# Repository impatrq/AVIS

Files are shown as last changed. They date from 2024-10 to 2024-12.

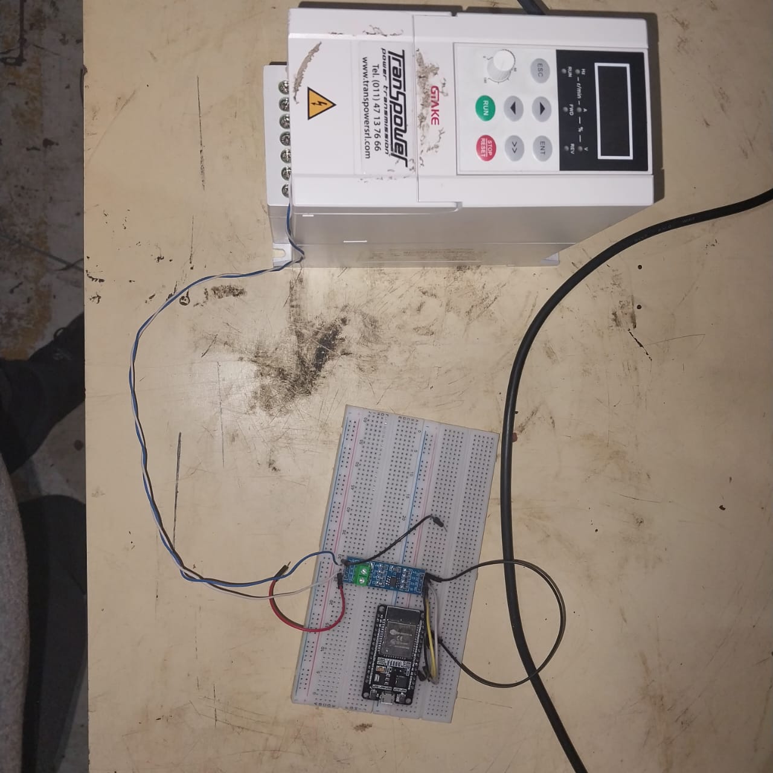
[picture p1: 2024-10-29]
variadores de frecuencia/pruebas con el osciloscopio/circuito.jpeg

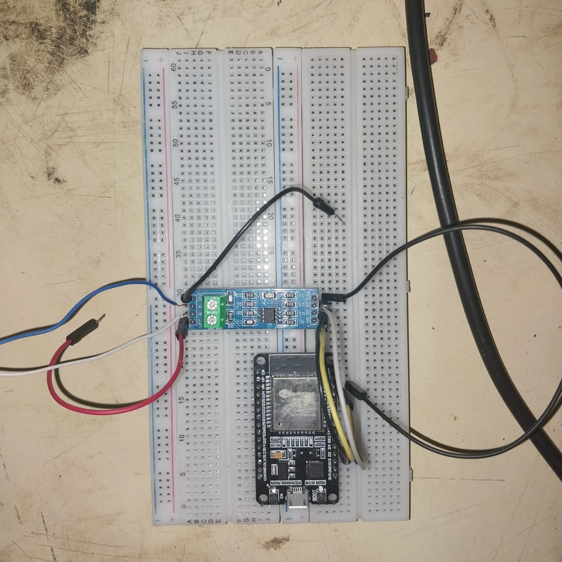
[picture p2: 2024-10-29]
variadores de frecuencia/pruebas con el osciloscopio/circuitov2.jpeg

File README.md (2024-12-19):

<div align="center">

# [S  K  Y  ⅃  ꟻ](https://estebanlautaro.github.io/Paginaweb-SKYFLY/)

Captura de pantalla 2024-11-19 194901

&nbsp;

| Página web | Email | Instagram | TikTok |
|---|---|---|---|
|[Paginaweb-SKYFLY](https://estebanlautaro.github.io/Paginaweb-SKYFLY/)|skyflyproyect@gmail.com|[skylf.proyect](https://www.instagram.com/skylf.proyect/)|[skyfly826](https://www.tiktok.com/@skyfly826)|

&nbsp;

</div>

## ¿De que se trata nuestro proyecto?

Nuestro proyecto es continuar con el simulador de vuelo que empezo el grupo llamado "AVIS" en 2019, destinado a practicar maniobras y replicar las condiciones de vuelo reales dentro de una cabina que simula los movimientos del avion. El propósito principal será facilitar la realización de prácticas didácticas, proporcionando a los usuarios un entorno seguro y controlado para mejorar sus habilidades de vuelo y familiarizarse con diferentes escenarios y situaciones aeronáuticas. Este tipo de simuladores se utilizan tanto con fines de entrenamiento de pilotos como para el entretenimiento de entusiastas de la aviación. Para mas informacion, entrar a las carpetas que estan en el repositorio.

## Tecnologías utilizadas 

### Entorno Virtual
- Flight Simulator 2020
- SimVar Watcher
  
### Software de programación
- ArduinoUNO
- Thonny

#### Drivers de ArduinoUNO
- ESP32_DEVKIT
- MPU6050_light

### Componentes 
- #### Placa PCB con:
  - ESP32 (30 pines)
  - MPU6050
  - Potenciometro digital X9C103S
  - Dos optoacopladores 4N25
  - Dos resistencias de 330 ohms
  - Dos resistencias de 10 Kohms
    
- #### Panel de Control:
  - Impresión 3D del Panel de Control
  - ArduinoUNO R3
  - Cable de Datos para el Arduino
  - 9 switches On/Off
  - 3 Pulsadores
  - Llave selectora de 6 estados

### Software del Panel de Control:
- Mobiflight
- FSUIPC

## Integrantes:

Somos un grupo de alumnos de 7°2da AV de la E.E.S.T. N°7 "Taller Regional Quilmes" (IMPA).

<div align="center">



</div>

### Lautaro Esteban

    📷 Instagram: @lauty.esteban
    📧 Email: lautyesteban14@gmail.com
    🗞️ LinkedIn: Lautaro Sebastian Esteban
    🌐 Github: https://github.com/estebanlautaro

### Agustin Brizuela:

    📷 Instagram: @agustiin.brizuela 
    📧 Email: brizuu750@gmail.com 
    🗞️ LinkedIn: Agustin Lionel Brizuela 
    🌐 Github: https://github.com/brizuu750

### Marco Jofiel Godoy Baldovino:

    📷 Instagram: @jofiel_godoy  
    📧 Email: markbaldj@gmail.com 
    🗞️ LinkedIn: Marco Baldovino
    🌐 Github: https://github.com/MarkingRNT

### Santiago Rubio:

    📷 Instagram: @santy_201205
    📧 Email: santy201205@gmail.com
    🗞️ LinkedIn: Santiago Rubio
    🌐 Github: https://github.com/SantiagoRubio

### Lucas David Meabrio:

    📷 Instagram: @lucass_meab
    📧 Email: meabriolucas@gmail.com
    🗞️ LinkedIn: Lucas Meabrio
    🌐 Github: https://github.com/LucasMeabrio

### Leandro Flores:

    📷 Instagram: @lean.floresss
    📧 Email: leandro200flores@gmail.com
    🗞️ LinkedIn: Leandro Flores
    🌐 Github: https://github.com/lean1712flores

### Santiago Leiva:

    📷 Instagram: @leivva.s
    📧 Email: santiagoleiva745@gmail.com 
    🗞️ LinkedIn: Santiago Leiva
    🌐 Github: https://github.com/SantyLeiva

### Emiliano Romo Cordoba:

    📧 Email: romoemiliano324@gmail.com
    🗞️ LinkedIn: Emiliano Romo Cordoba 
    🌐 Github: https://github.com/RomoCordoba

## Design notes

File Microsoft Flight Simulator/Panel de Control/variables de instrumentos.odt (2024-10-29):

INSTRUMENTOS:

velocimetro

no confundir airspeed indicated con true, me parece que se usa la indicada

altimetro

variometro (indicador de velocidad vertical)

horizonte artificial:

según chatgpt

lo que encontre yo es esto

si esta congelado y un flag, es el attitude indicator en ingles

brujula (giro direccional??? quien le dice asi xd)

~~NO~~ usar

turn indicator:

no estoy 100% seguro que ese se use el de arriba

NAV LOC

NAV VOR/ GLIDE SLOPE(GS)

ahora el gs

preparate para el adf xd

reloj

no encontre, no tengo ni idea

amperimetro/voltimetro

si quieren poner esto en el panel pidanlo

temp y presion de aceite

no se la diferencia entre estos y los que vienen

SI USAR

temp de gas de escape y flujo de combustiblre

egt = exhaust gas temperature = temp d gas de escape

ind combustible

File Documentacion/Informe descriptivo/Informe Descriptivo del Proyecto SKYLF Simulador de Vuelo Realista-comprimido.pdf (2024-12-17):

# Informe Descriptivo del Proyecto SKYLF: Simulador de Vuelo Realista

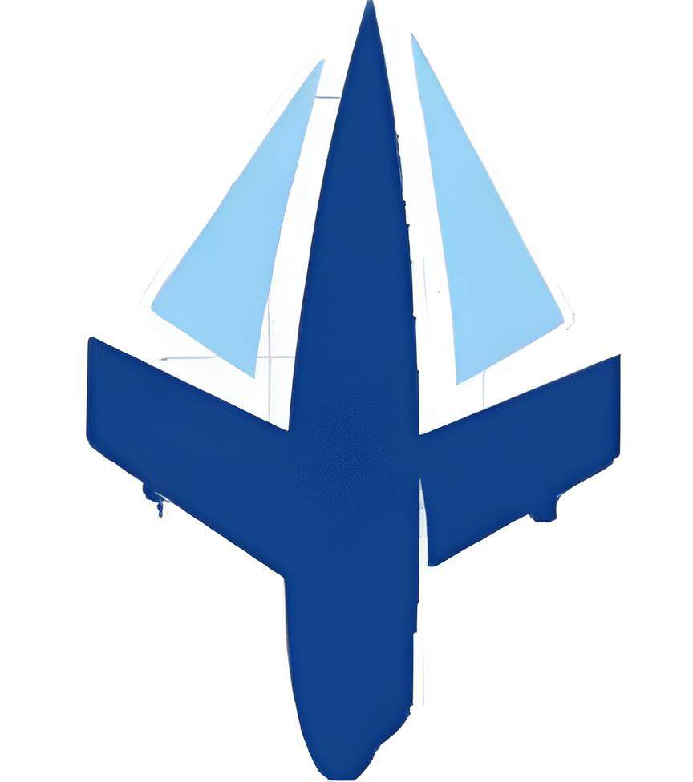
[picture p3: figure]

## Título:

Simulador de Vuelo Realista con Control de Variadores de Frecuencia y Panel de Instrumentos Físicos

## Nombre del Proyecto y Año:

SKYFLY - 7° 2° Aviónica

## Link a la Web:

https://estebanlautaro.github.io/Paginaweb-SKYFLY/

## Link a Trello:

https://trello.com/b/u9Dn0bU8/kanban

## Link a GitHub:

https://github.com/brizuu750/SKYLF

## Link a Redes Sociales:

●
Instagram: | https://www.instagram.com/skylf.proyect/
- Tiktok: | https://www.tiktok.com/@skyfly826?_t=8qnCGQhRKsA&_r=1

## Presentación del Equipo:

Lauaro Eseban:

Mail: Lautyesteban14@gmail.com

Linkedin: Lautaro Sebastian Esteban

Instagram: @lauty.esteban

Santiago Rubio:

Mail: Santy201205@gmail.com

Linkedin: Santiago Rubio

Instagram: @santy_201205

Lucas Meabrio:

Mail: Meabriolucas@gmail.com

Linkedin: Lucas Meabrio

Instagram: @lucass_meab

Leandro Flores:

Mail: leandro200flores@gmail.com

Linkedin: Leandro Flores

Instagram: @lean.floresss

Agustin Brizuela:

Mail: brizuu750@gmail.com

Linkedin: Agustin Lionel Brizuela

Instagram: @agustiin.brizuela

Santiago Leiva:

Mail: Santiagoleiva745@gmail.com

Linkedin: Santiago Leiva

Instagram: @leivva.s

Emiliano Romocordoba:

Mail: Romoemiliano324@gmail.com

Linkedin: Emiliano Romo Cordoba

Jofiel Godoy Baldovino:

Mail: Markbaldj@gmail.com

Linkedin: Marco Baldovino

Instagram:@jofiel_godoy

## Foto de cada integrante:

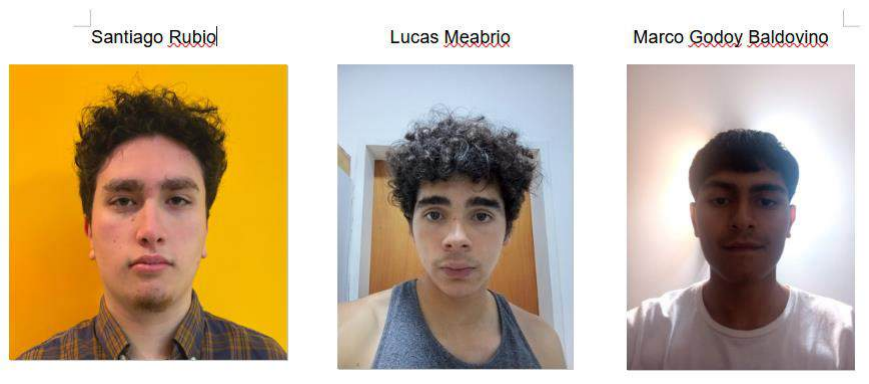
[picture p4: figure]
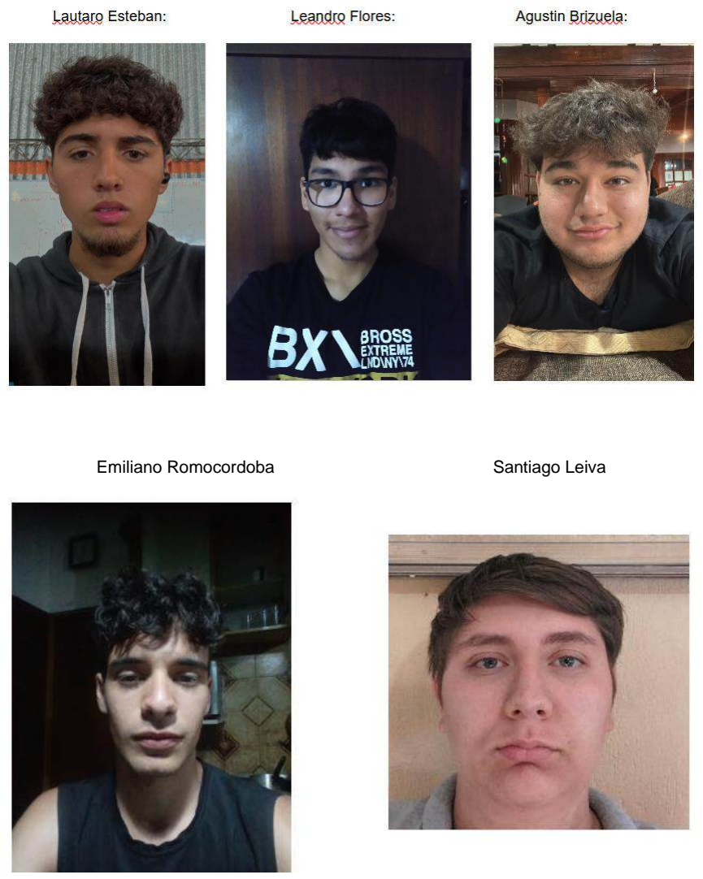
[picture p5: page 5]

Emiliano Romocordoba | Santiago Leiva

Foto grupal:

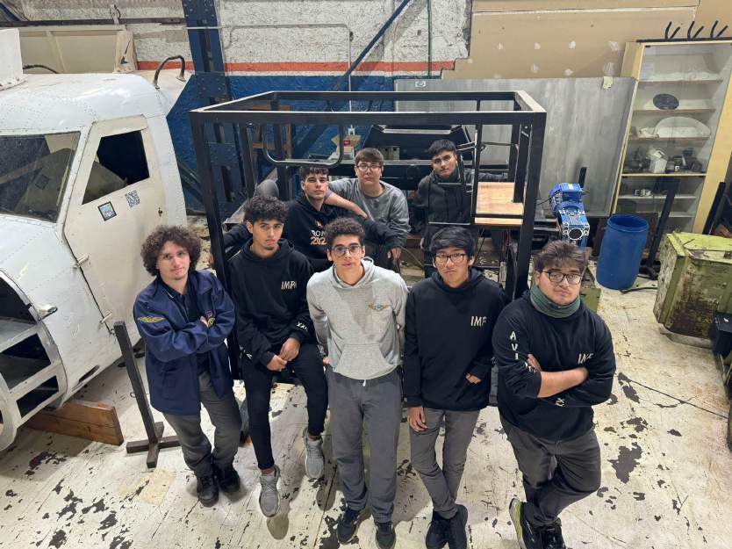
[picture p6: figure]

## Horas dedicadas por cada integrante:

Participaron un total de 8 personas en un promedio de 14 hs semanales durante 28 semanas aproximadamente

## Índice General

1. Introducción
2. Objetivo
3. Descripción de la Solución Buscada
4. Segmento Destino y Alcance
5. Captura Representativa del Proyecto
6. Diagrama en Bloques del Proyecto
7. Resultado Conseguido
8. Software
9. Sistema Embebido
10. Electrónica
11. Estructura
12. Anexo

## 1. Introducción

Este proyecto de Simulador de Vuelo Realista, basado en la cabina del Cessna 152, replica las maniobras y controles de la aeronave mediante la integración de un panel físico de control y un sistema de visualización interactuando con Flight Simulator 2020. Se implementa un circuito de comunicación mediante un Arduino UNO y un ESP32 que permiten gestionar diversos sistemas y enviar comandos a través de variables de comunicación específicas, sincronizando los instrumentos físicos con el simulador virtual. Además, el simulador utiliza un sistema de control de motores con variadores de frecuencia y sensor de movimiento MPU6050 para añadir realismo en el control de vuelo.

## 2. Objetivo

Objetivo General:

Construir un simulador de vuelo con una interfaz de usuario realista, que permita experimentar el control de una aeronave tipo Cessna 152 mediante un panel físico conectado a Flight Simulator 2020.

Objetivo Específico:

Integrar un sistema de variadores de frecuencia, Arduino UNO y ESP32, junto con un panel de control que permita al usuario activar sistemas de vuelo, como el control de luces, bomba de combustible y buses aviónicos, replicando el entorno real de un avión en el simulador virtual.

## 3. Descripción de la Solución

El simulador incluye dos sistemas principales: un Panel de Control y un Panel de Visualización de Instrumentos, con un esquema de comunicación que integra varios componentes para emular los controles de un avión real.

Panel de Control

El Panel de Control cuenta con 9 interruptores de palanca, 3 pulsadores, y una llave selectora rotativa de 6 estados. Este panel físico permite al usuario activar sistemas esenciales de la aeronave en el entorno virtual de Flight Simulator 2020, mediante la integración de MobiFlight y Arduino UNO. Algunos de los sistemas principales controlados por el panel incluyen:

- Bomba de Combustible: Activa una bomba de combustible que permite el cebado inicial del motor.

- Luces (BCN, LAND, TAXI, NAV, STRB): Controla las luces exteriores del avión para el despegue, aterrizaje y condiciones de vuelo específicas.
- Interruptores de Bus Aviónico: Activa los sistemas de navegación y comunicación de la aeronave.
- Tubo Pitot: Controla el calentador del tubo Pitot para evitar el congelamiento.
- Primer: Se encarga de inyectar combustible a los cilindros del motor antes de arrancarlo, facilitando el arranque en condiciones especialmente frías.
- Magnetos: Distribuyen corriente eléctrica a las bujías, gestionadas por una llave rotativa de 6 estados. Para comunicar la llave selectora tuvimos que hacer un código que se encargue de mandar los “Events id” para las posiciones del magneto dependiendo de la actual posición de la llave selectora ya que al usar Mobiflight, algunas posiciones son erróneas (se utilizan como una forma de interactuar entre diferentes sistemas del simulador), pero en el código las posiciones andan bien. Las partes más importantes del código son:

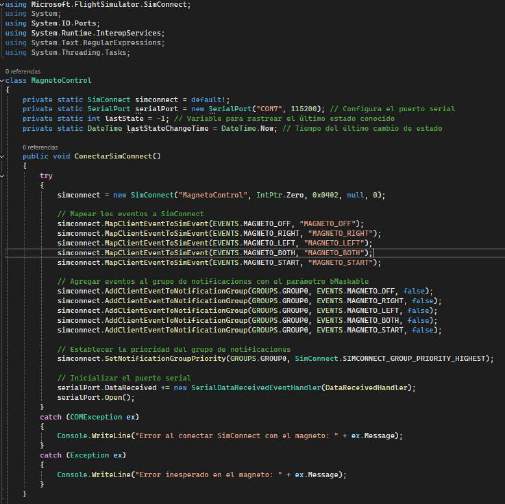
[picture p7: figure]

Se ingresan las librerías necesarias y los events id que se van a usar:

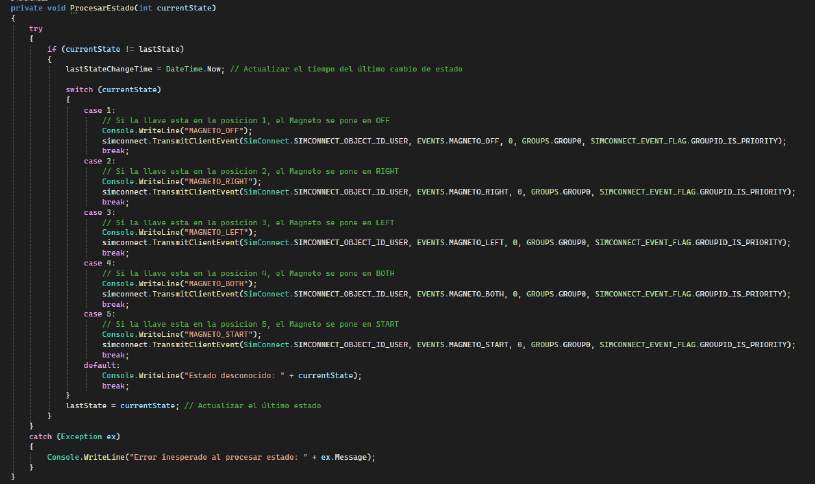
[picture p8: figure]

El código enviá estos events id al propio Flight Simulator dependiendo de la posición de la llave selectora

El Arduino UNO es el microcontrolador principal del panel de control y se configura mediante MobiFlight para ejecutar comandos específicos en Flight Simulator 2020 según los interruptores activados. Esto asegura que cada acción en el panel tenga un reflejo preciso en el simulador virtual, mejorando la inmersión en el entorno de vuelo.

Paso a Paso de configuración de palancas para vincularlas con MobiFlight y el FS2020:

1. Conectamos el Arduino UNO al MobiFlight y el FSUIPC7
2. Asignamos un Pin del 2 al 13 del Arduino UNO a uno de los terminales de la palanca (En nuestro caso lo pusimos al pin 8 pero puede ser cualquiera)
3. Seleccionar en MobiFlight la pestaña de "MobiFlight Modules"
4. Para no tener inconvenientes actualizar el firmware así el MobiFlight detecte correctamente el la Arduino UNO
5. En la barra inferior ir a la pestaña de "Add Device" para agregar un dispositivo que en nuestro caso es una palanca.
6. Luego le asignamos a la palanca el nombre con el que queramos que se identifique, siendo en este caso "Tubo Pitot" para la función de la palanca que es sobre el Calentador del Tubo Pitot

7. Poner en la "Configuración de Pin" el pin que le asignamos a la palanca (en nuestro caso el Pin 8 de la Arduino UNO)
8. En el Menú principal crear una configuración de entrada en el "Input Configs"
9. Para editar la configuración selecciona a la derecha de la fila en "Edit"
10. Luego seleccionar los dispositivos conectados al MobiFlight
11. Seleccionar en el Action Type el "FSUIPC - Offset" para luego asignarle la acción al dispositivo que hayamos conectado (en nuestro caso la palanca)
12. Dentro de la configuración de entrada se encuentran las configuraciones para cuando se activa la palanca "On Press" y cuando está del lado contrario "On Release"
13. Para la configuración del Offset nos fijamos en el manual de Offset del FSUIPC que está en internet para buscar la acción de la palanca, y nos dice cuál código de Offset tiene que ir.
14. En nuestro caso buscamos el del calentador del tubo pitot. Por lo que ponemos el que nos dice "029C"
15. Para que el Calentador del tubo pitot del Cessna 152 se active en simultáneo a la palanca que conectamos al FS2020, le asignamos "1" como valor de seteo.
16. En "On Release" de igual forma poner el mismo código de Offset pero que cuando se baje la palanca que el calentador se apague ponemos "0" como valor de seteo
17. Luego de esto al probar la palanca que vinculamos a dispositivo que sea (en nuestro caso el calentador del tubo pitot), se tendría que activar simultáneamente

Comunicación con el Variador de Frecuencia y Sistema de Control de Movimiento

Para lograr una experiencia de vuelo más realista, el simulador utiliza un variador de frecuencia GK500-2T2.2B controlado por un ESP32 y un potenciómetro digital para gestionar el movimiento de los motores, lo que permite simular inclinaciones en los ejes de cabeceo y alabeo. La configuración del variador de frecuencia y el sistema de comunicación están organizados de la siguiente forma:

- ESP32 y Potenciometro digital: El ESP32 envía comandos al potenciómetro digital a través de los pines de control (UP, DOWN, CS) para ajustar su resistencia.El potenciómetro digital modifica los valores eléctricos que afectan directamente el comportamiento de los variadores de frecuencia, lo que impacta en el movimiento de los motores trifásicos y, en consecuencia, en la inclinación de la cabina del simulador.
- Configuración de Pines:
- Conexión del MPU6050:

- VCC del MPU6050 a 3.3V del ESP32.
- GND del MPU6050 a GND del ESP32.
- SDA del MPU6050 a GPIO21 del ESP32.
- SCL del MPU6050 a GPIO22 del ESP32.
- Conexión de los Potenciómetros Digitales
a. Para el primer potenciómetro:
- CS_PIN a GPIO15 del ESP32.
- INC_PIN a GPIO14 del ESP32.
- UP_DOWN_PIN a GPIO13 del ESP32.
- VW va al GND del variador 1
- VH y VL van a dos pines del variador 1
- VCC del potenciómetro a la entrada analógica del variador 1 (AI1).
- GND del potenciómetro a GND común del variador 1
b. Para el segundo potenciómetro:
- CS_PIN a GPIO32 del ESP32.
- INC_PIN a GPIO33 del ESP32.
- UP_DOWN_PIN a GPIO25 del ESP32.
- VW va al GND del variador 2
- VH y VL van a dos pines del variador 2
- VCC del potenciómetro a la entrada analógica del variador 2 (AI1).
- GND del potenciómetro a GND común del variador 2.
- Conexión de los optoacopladores y resistencias:
a. Para el primer optoacoplador:
- Anodo del led va a la primera resistencia de 330 Ω y luego al GPIO27 del ESP32
- Cátodo del led va a GND del esp32
- Colector va conectado a el puerto x1 del variador 1 y también conectado a la primera resistencia de 10 KΩ y luego va al VCC de la fuente
- Emisor del optoacoplador va a COM del variador 1 y también va a GND de la fuente
b. Para el segundo optoacoplador:
- Anodo del led va a la segunda resistencia de 330 Ω y luego al GPIO12 del ESP32
- Cátodo del led va a GND del esp32
- Colector va conectado a el puerto x2 del variador 1 y también está conectado a la segunda resistencia de 10 KΩ y luego va al VCC de la fuente
- Emisor del optoacoplador va a COM del variador 1 y también va a GND de la fuente
c. Para el tercer optoacoplador:

- Anodo del led va la tercera resistencia de 330 Ω y luego al GPIO18 del ESP32
- Cátodo del led va a GND del esp32
- Colector va conectado a el puerto x1 del variador 2 y también está conectado a la tercera resistencia de 10 KΩ y luego va al VCC de la fuente
- Emisor del optoacoplador va a COM del variador 2 y también va a GND de la fuente
d. Para el cuarto optoacoplador:
- Anodo del led va la cuarta resistencia de 330 Ω y luego al GPIO19 del ESP32
- Cátodo del led va a GND del esp32
- Colector va conectado a el puerto x2 del variador 2 y también está conectado a la cuarta resistencia de 10 KΩ y luego va al VCC de la fuente
- Emisor del optoacoplador va a COM del variador 2 y también va a GND de la fuente
3. Sensor de Movimiento MPU6050: Integrado al ESP32, el MPU6050 detecta la inclinación y aceleración en tiempo real, lo que permite ajustar los movimientos del simulador para reflejar las maniobras de vuelo de manera más precisa. Este sensor es crucial para sincronizar el sistema físico con los cambios en el entorno virtual del Flight Simulator 2020.

Panel de Visualización de Instrumentos

Este panel de visualización está diseñado para mostrar los datos de vuelo en una pantalla de 18 pulgadas, reflejando los instrumentos de la aeronave. La comunicación de los datos de vuelo se realizaría mediante Air Manager o Pop Out Panel Manager, que gestionan las variables de Flight Simulator 2020. Este diseño permite una representación en tiempo real de los parámetros del simulador, ajustando el diseño para que se asemeje al de un Cessna 152.

Flight Simulator 2020

Utilizamos Microsoft Flight Simulator - 40th Anniversary Edition, compatible con herramientas externas de comunicación que extraen variables en tiempo real, como Simvar Watcher.

Simvar Watcher y Extracción de Variables

El Simvar Watcher facilita la lectura de variables seleccionadas del simulador, configurado con las librerías SimConnect y otros archivos DLL y CFG, permitiendo acceder a las lecturas en tiempo real. Las variables se agrupan para la lectura de datos de instrumentos (altímetro, velocímetro, etc.) y control de movimiento.

Para la integración de Simvar Watcher con Flight Simulator, utilizamos códigos en C# en Visual Studio 2022. Estos códigos gestionan la conexión y extracción de

variables, que se dividen según los instrumentos que controlan (altímetro, brújula, velocímetro, etc) y un código para los movimientos y aceleraciones del avión.

Códigos Generales:

- Program.cs: Este código configura y gestiona la comunicación entre el simulador de vuelo y múltiples sistemas de instrumentos y controles, permitiendo que cada uno reciba y procese datos en tiempo real.
- SimConnectApp.csproj: Este código configura un proyecto de .NET 8.0 que genera un ejecutable (Exe) para la plataforma x64. Define referencias y dependencias necesarias, incluyendo System.IO.Ports para manejar la comunicación por puertos seriales y SimConnect para interactuar con Microsoft Flight Simulator. También, especifica la ruta de salida para los binarios compilados y define un objetivo post-construcción que copia los archivos SimConnect.dll y SimConnect.cfg necesarios a la ubicación de salida del proyecto.

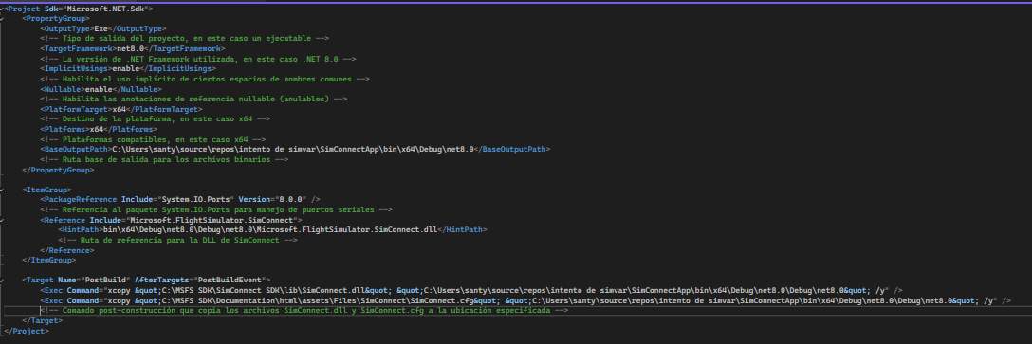
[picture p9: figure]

Códigos de Instrumentos:

Cada instrumento está asignado a un código específico que se comunica con el simulador. Los siguientes están hechos para ser comunicados con una aplicación externa, como el Air Manager en caso de los instrumentos analógicos, y en caso de que se desee añadir alguno digital, se pueden encontrar variantes a este como el pop out manager. Además, son los encargados de la sincronización con mobilight, por lo que permite que funcionen tanto el panel de instrumentos como el de control. Por ejemplo:

Altímetro.cs: Extrae la altura en tiempo real.

Variómetro.cs: Controla la velocidad vertical del avión.

Velocímetro.cs: Muestra la velocidad de vuelo.

BrujulaMagnetica.cs: Muestra la dirección cardinal (N, S, E, O) en la que se encuentra el avión.

CoordinadorDeGiro.cs: Indica la tasa de giro del avión y ayuda a mantener un giro coordinado.

HorizonteArtificial.cs: Representa la orientación del avión respecto al horizonte real.

ILS.cs: Muestra las indicaciones del sistema de aterrizaje por instrumentos (Instrument Landing System).

IndicadorADF.cs: Indica la dirección hacia una estación de radio NDB (Non-Directional Beacon).

IndicadorCombustible.cs: Monitorea el nivel de combustible del avión.

IndicadorDeBateria.cs: Mide y muestra el estado de la batería del avión.

IndicadorRPM.cs: Mide y muestra las revoluciones por minuto del motor.

IndicadorTemp_PresionAceite.cs: Monitorea la temperatura y presión del aceite del motor.

IndicadorVOR.cs: Indica la dirección hacia una estación VOR (VHF Omnidirectional Range)

Código para movimientos y aceleraciones del avión (Comparaciones.cs):

El código se encargará de comunicarse con ciertas variables para el pitch, bank y las aceleraciones (excepto el eje Z, ya que no hay motor que se mueva en ese eje). También se encarga de recibir los datos del mpu6050 y de transformar el giro X e Y en el ángulo donde estaría el mpu en cada momento, y de transformar las aceleraciones de fuerza G a ft/s

2
. Luego el codigo compara de 4 formas diferentes los valores de las variables con los valores del mpu6050 y, dependiendo de la diferencia entre los valores, el código se encarga de mandar diferentes comandos (como MOVER_IZQUIERDA y MOVER_ABAJO) al ESP32 para que luego este se los envíe a los variadores de frecuencia.

Las partes más importantes del código son:

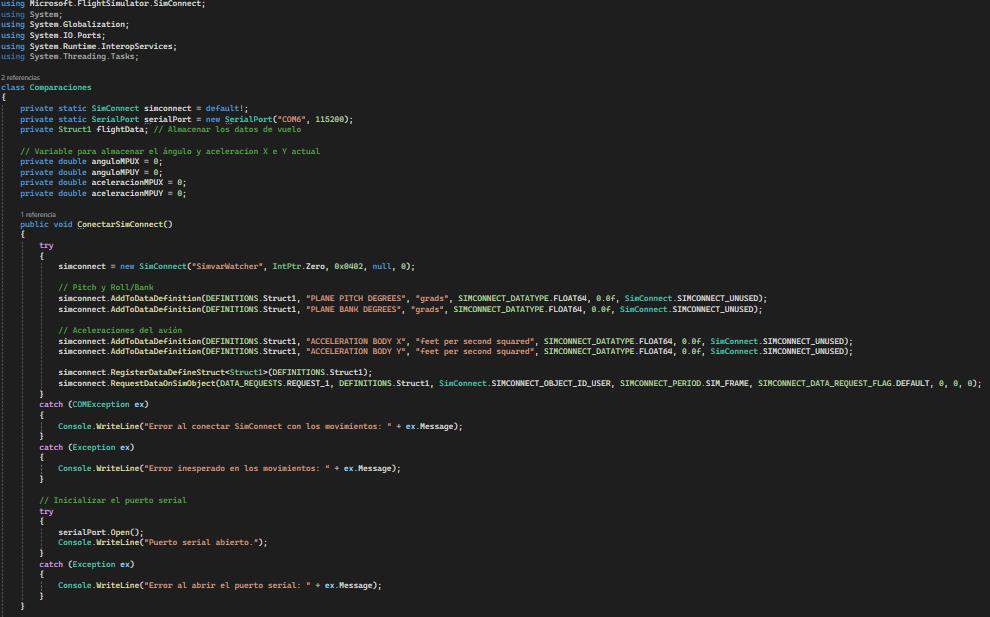
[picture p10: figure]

Se incluye las librerías necesarias y se extrae las variables del pitch, bank y las aceleraciones

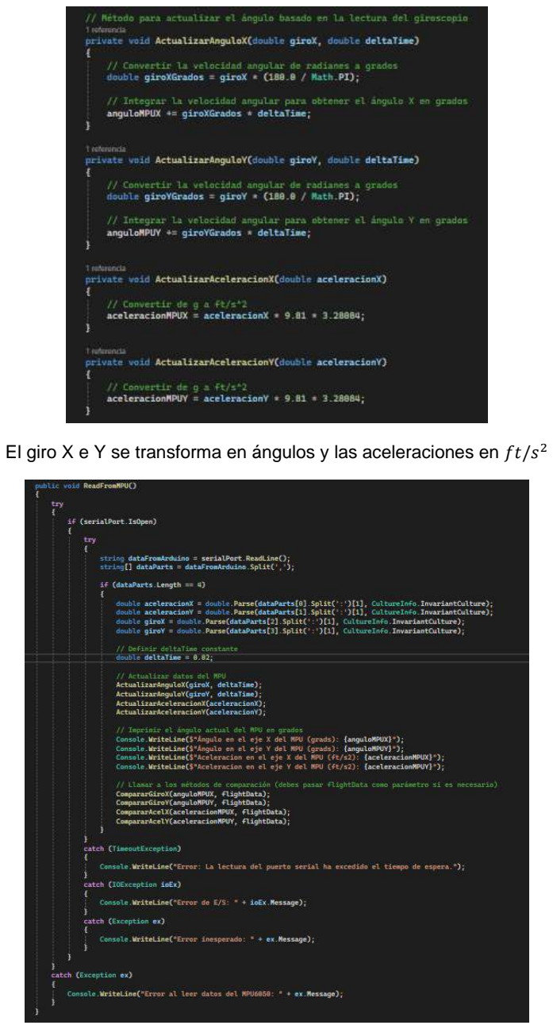
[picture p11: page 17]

El giro X e Y se transforma en ángulos y las aceleraciones en ft/s

2

Esta función se encarga de recibir los datos del mpu6050 y llamar a los distintos metodos de comparacion

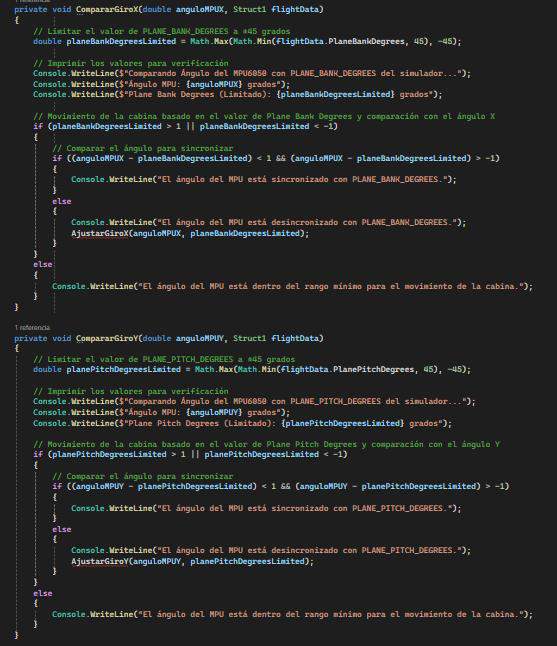
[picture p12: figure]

En estas funciones se compara los valores del ángulo X e Y del mpu y de las variables del pitch y bank para obtener la diferencia entre ellos.

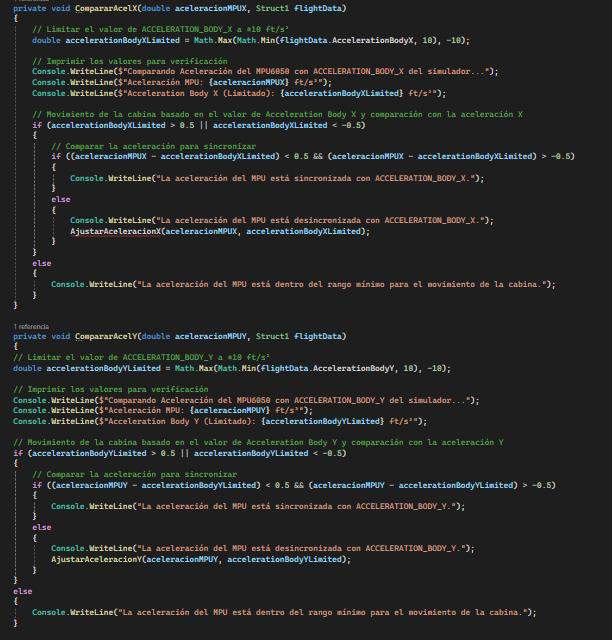
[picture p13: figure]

En estas funciones se compara los valores de la aceleración X e Y del mpu y de las variables de las aceleraciones X e Y del avión para obtener la diferencia entre ellos.

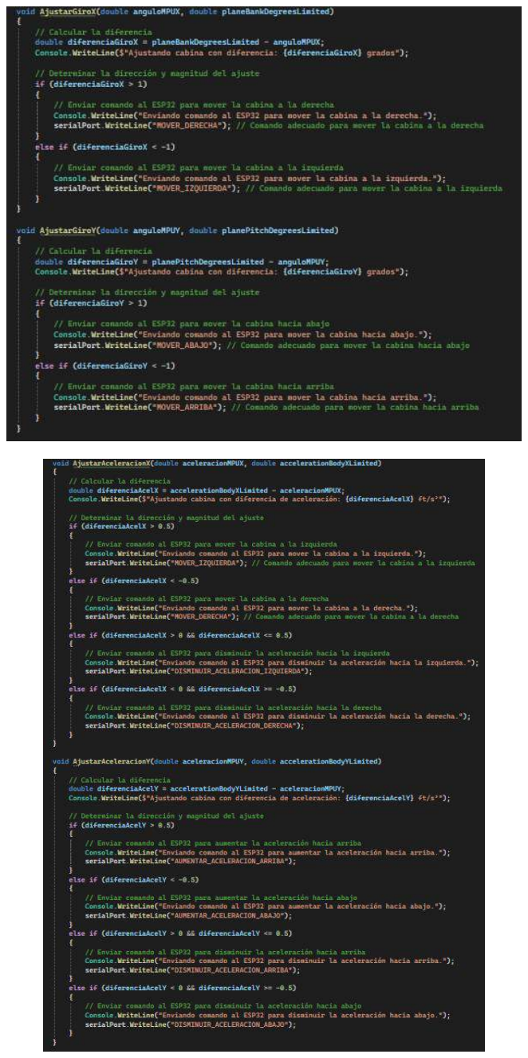
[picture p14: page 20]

Estas funciones leen la diferencia todo momento y mandan comandos dependiendo del valor de la diferencia

## 4. Segmento Destino y Alcance

Este simulador está destinado a estudiantes de ingeniería, entusiastas de la aviación y centros de enseñanza técnica que busquen herramientas de formación práctica en sistemas de control, mecánica de vuelo y electrónica aplicada. El proyecto tiene el potencial de ser una plataforma educativa completa en simulación de vuelo.

## 5. Captura Representativa del Proyecto

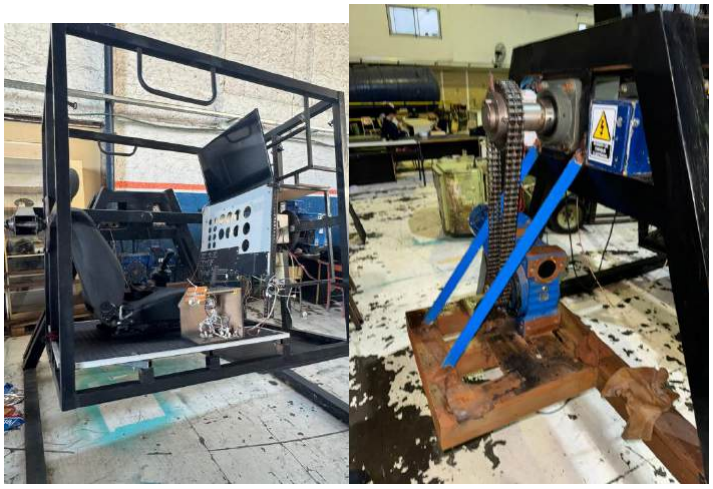
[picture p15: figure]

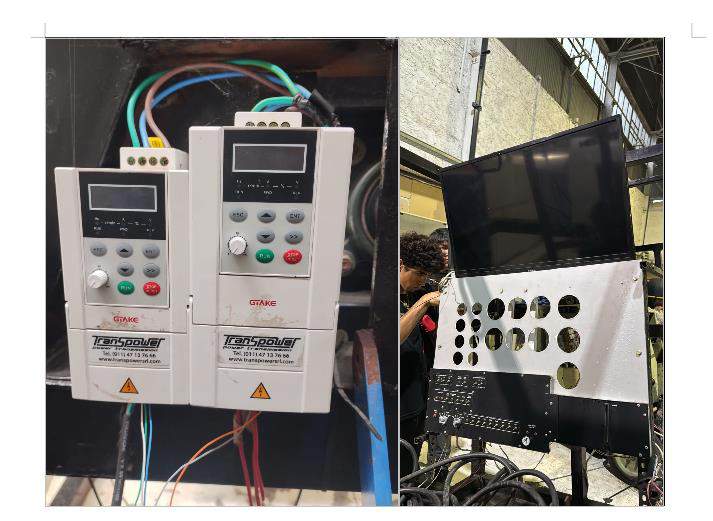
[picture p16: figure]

## 6. Diagrama en Bloques del Proyecto

## Diagrama general:

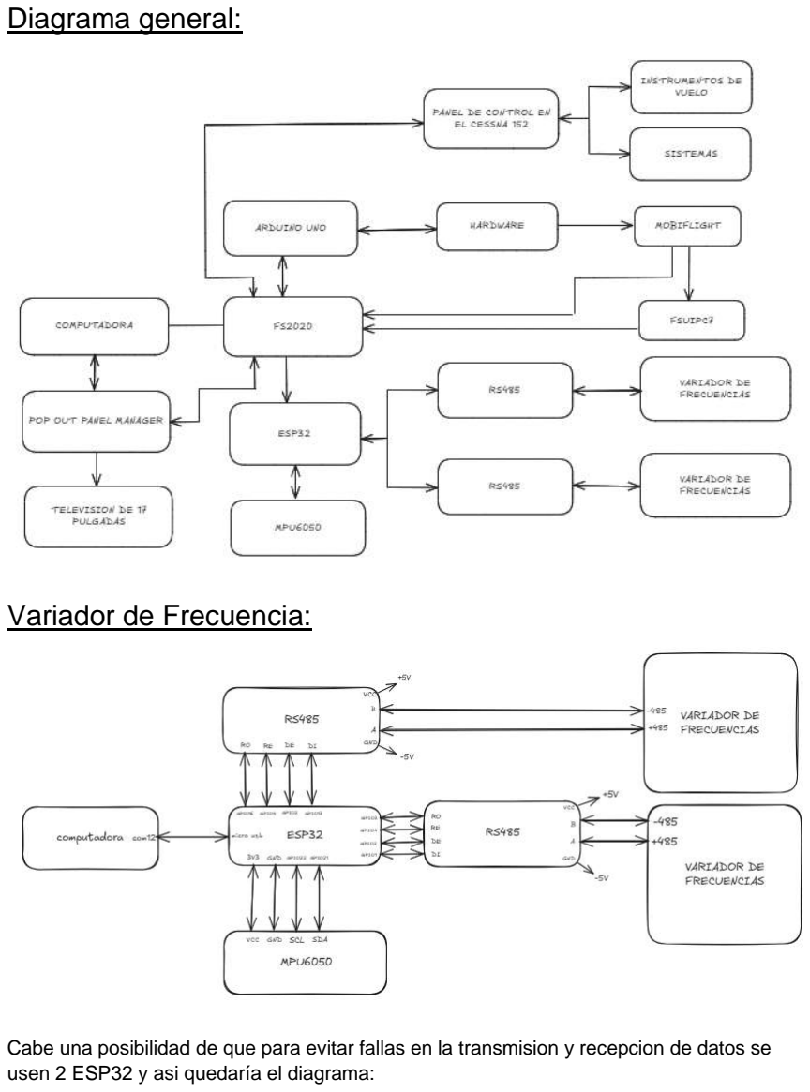
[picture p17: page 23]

## Variador de Frecuencia:

Cabe una posibilidad de que para evitar fallas en la transmision y recepcion de datos se usen 2 ESP32 y asi quedaría el diagrama:

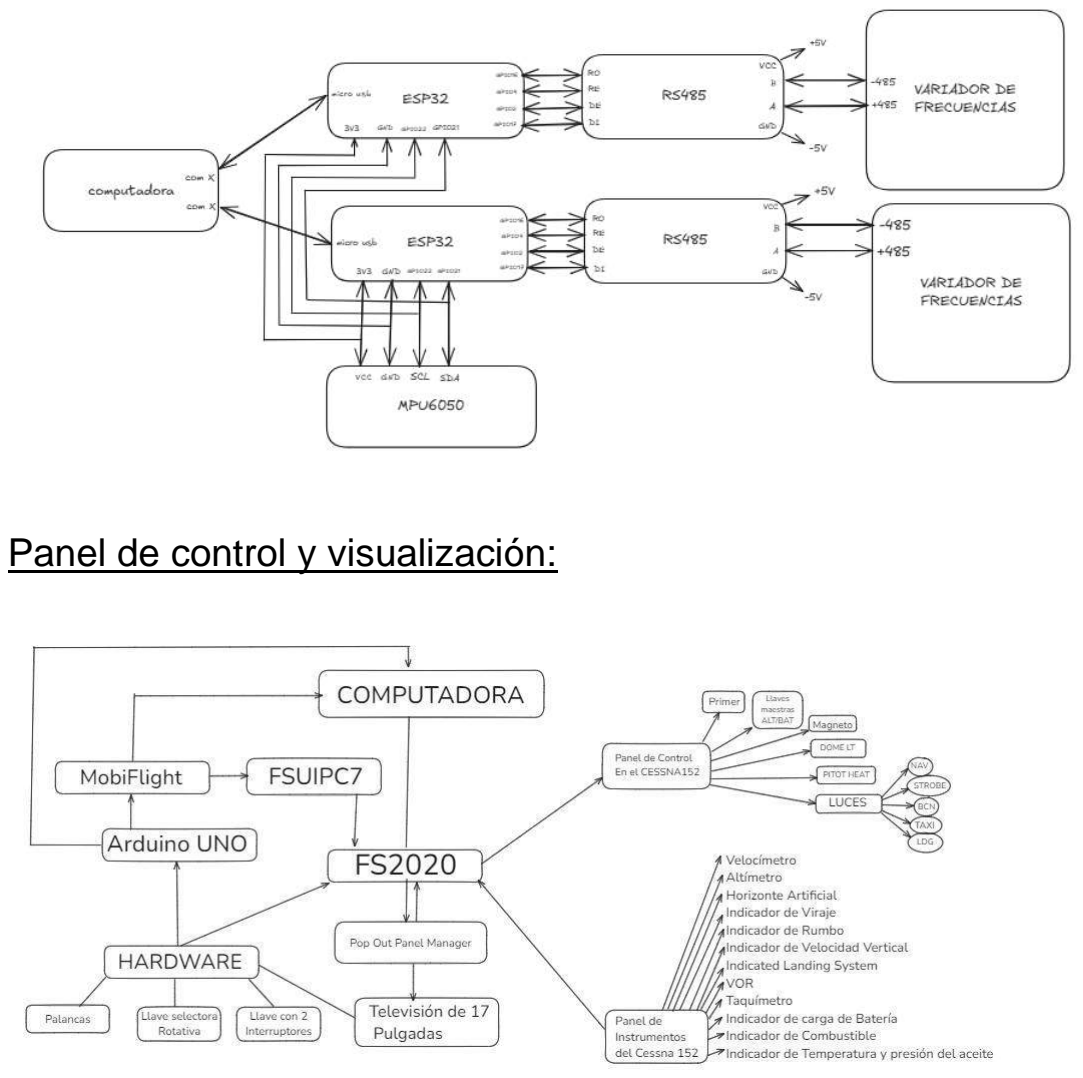
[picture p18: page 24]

## Panel de control y visualización:

## Conexiones del ArduinoUNO al Panel de control:

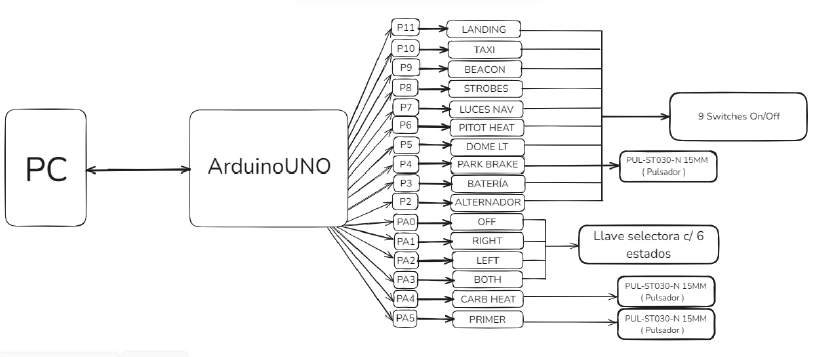
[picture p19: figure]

## 7. Resultados Conseguidos

Se trabaja en la implementación de la conexión y funcionamiento del panel de control con Flight Simulator 2020. Las pruebas iniciales de los motores todavía están en proceso. El sistema continúa en fase de pruebas y optimización, principalmente en el uso de variables de comunicación para mejorar la precisión de las lecturas y comandos en tiempo real, y también la comunicación con el variador de frecuencias

## 8. Software

Lenguajes Utilizados:

- C/C++: Programación del ESP32 y Arduino UNO para la comunicación con los variadores de frecuencia.
- C/C++: Programación del Arduino UNO para gestionar los interruptores.

Capturas de Códigos Significativos:

Código de prueba entre el ESP32 y el Potenciómetro digital:

// Pines de conexión para el AR-X9C103S
const int CS_PIN = 15; | // Chip Select
const int INC_PIN = 14; | // Incremento
const int UP_DOWN_PIN = 13; // Dirección (incremento o decremento)

int targetFrequency = 0; // Frecuencia deseada introducida por el usuario

void setup() {
// Configuración de los pines de control
pinMode(CS_PIN, OUTPUT);
pinMode(INC_PIN, OUTPUT);

pinMode(UP_DOWN_PIN, OUTPUT);

// Inicializar los pines en estado alto digitalWrite(CS_PIN, HIGH); digitalWrite(INC_PIN, HIGH); digitalWrite(UP_DOWN_PIN, HIGH);

Serial.begin(115200);
Serial.println("Introduce la frecuencia deseada en el Monitor Serie:"); }

void loop() {
// Comprobar si hay datos en el Monitor Serie
if (Serial.available() > 0) {
targetFrequency = Serial.parseInt(); // Leer la frecuencia ingresada por el usuario Serial.print("Frecuencia recibida: ");
Serial.println(targetFrequency);

// Ajustar la resistencia en función de la frecuencia adjustResistance(targetFrequency);
}
delay(500); // Pausa para evitar lecturas rápidas consecutivas }

void adjustResistance(int frequency) {
int steps = map(frequency, 0, 100, 0, 100); // Mapear frecuencia a pasos (ajustar según tu rango)

// Incrementar la resistencia del potenciómetro al máximo
Serial.println("Ajustando resistencia...");
digitalWrite(UP_DOWN_PIN, HIGH); // Configurar para incrementar digitalWrite(CS_PIN, LOW); // Activar el potenciómetro

for (int i = 0; i < steps; i++) {
pulseIncrement();
delay(50); // Pausa entre pasos para observar el cambio
}

digitalWrite(CS_PIN, HIGH); // Desactivar el potenciómetro }

void pulseIncrement() {
digitalWrite(INC_PIN, LOW);
delayMicroseconds(1); // Pulso corto para cambiar el valor digitalWrite(INC_PIN, HIGH);
delayMicroseconds(1);
}

Código de prueba entre el ESP32 y el Potenciómetro digital con el MPU6050:

#include <Wire.h>

#include <MPU6050.h>

MPU6050 mpu;

// Pines de conexión para el AR-X9C103S
const int CS_PIN = 15; | // Chip Select
const int INC_PIN = 14; | // Incremento

const int UP_DOWN_PIN = 13; // Dirección (incremento o decremento)

// Rango de ángulo para mapear a la resistencia del potenciómetro const int ANGLE_MIN = -90;
const int ANGLE_MAX = 90;

// Variables para el control de resistencia
int lastSteps = -1; // Valor previo de pasos del potenciómetro const float DEADZONE_MIN = -1.0;
const float DEADZONE_MAX = 1.0;

void setup() {
Serial.begin(115200);
Serial.println("Iniciando el MPU6050 y el potenciómetro digital.");

// Configuración de los pines de control
pinMode(CS_PIN, OUTPUT);
pinMode(INC_PIN, OUTPUT);
pinMode(UP_DOWN_PIN, OUTPUT);

// Inicializar los pines en estado alto digitalWrite(CS_PIN, HIGH); digitalWrite(INC_PIN, HIGH); digitalWrite(UP_DOWN_PIN, HIGH);

// Inicializar la comunicación I2C con el MPU6050 Wire.begin();
mpu.initialize();

// Comprobar conexión con el MPU6050
if (mpu.testConnection()) {
Serial.println("MPU6050 conectado correctamente.");
} else {
Serial.println("Error al conectar el MPU6050. Verifica las conexiones."); }
}

void loop() {
int16_t ax, ay, az;
mpu.getAcceleration(&ax, &ay, &az);

// Calcular el ángulo aproximado en el eje X float angleX = atan2(ay, az) * 180 / PI;

// Aplicar punto muerto
if (angleX > DEADZONE_MIN && angleX < DEADZONE_MAX) { // Si el ángulo está en el rango del punto muerto, no hacer ajustes return;
}

// Mapear el ángulo al rango de pasos del potenciómetro (0 a 99) int steps = map(angleX, ANGLE_MIN, ANGLE_MAX, 0, 99);

// Solo ajustar si el valor de pasos ha cambiado
if (steps != lastSteps) {
Serial.print("Ángulo X: ");
Serial.print(angleX);
Serial.print(" | Ajustando a pasos del potenciómetro: ");

Serial.println(steps);

adjustResistanceSmoothly(steps); lastSteps = steps;
}

// Reducir el retraso para actualizaciones más continuas delay(10);
}

void adjustResistanceSmoothly(int targetSteps) {
// Determina la dirección según el cambio necesario bool increment = targetSteps > lastSteps; digitalWrite(UP_DOWN_PIN, increment ? HIGH : LOW); digitalWrite(CS_PIN, LOW); // Activar el potenciómetro

// Cambia un paso a la vez para hacer el ajuste suave int stepDifference = abs(targetSteps - lastSteps);
for (int i = 0; i < stepDifference; i++) {
pulseIncrement();
delay(5); // Pausa corta para cada pulso, ajustable para mayor fluidez }

digitalWrite(CS_PIN, HIGH); // Desactivar el potenciómetro Serial.println("Resistencia ajustada suavemente.");
}

void pulseIncrement() {
digitalWrite(INC_PIN, LOW);
delayMicroseconds(1); // Pulso corto para cambiar el valor digitalWrite(INC_PIN, HIGH);
delayMicroseconds(1);
}

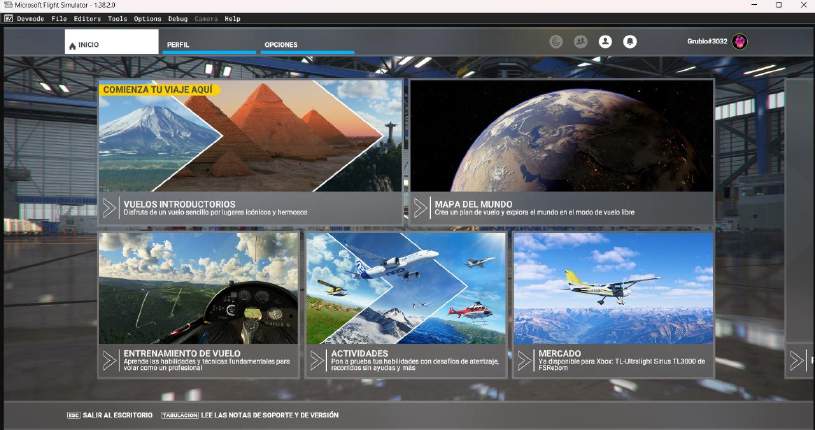
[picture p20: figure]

Captura de interfaz visual:

Estructuras de Datos:

Las librerías principales usadas en el variador de frecuencias son:

- MPU6050_light: Esta librería está diseñada para facilitar el uso del sensor MPU6050, que combina un acelerómetro y un giroscopio en un solo módulo. Esta librería es una versión optimizada y ligera para Arduino.

Lista de variables del Flight Simulator 2020

Variables de instrumentos:

- Altímetro:
- Brújula Magnética:
- Coordinador de giro:

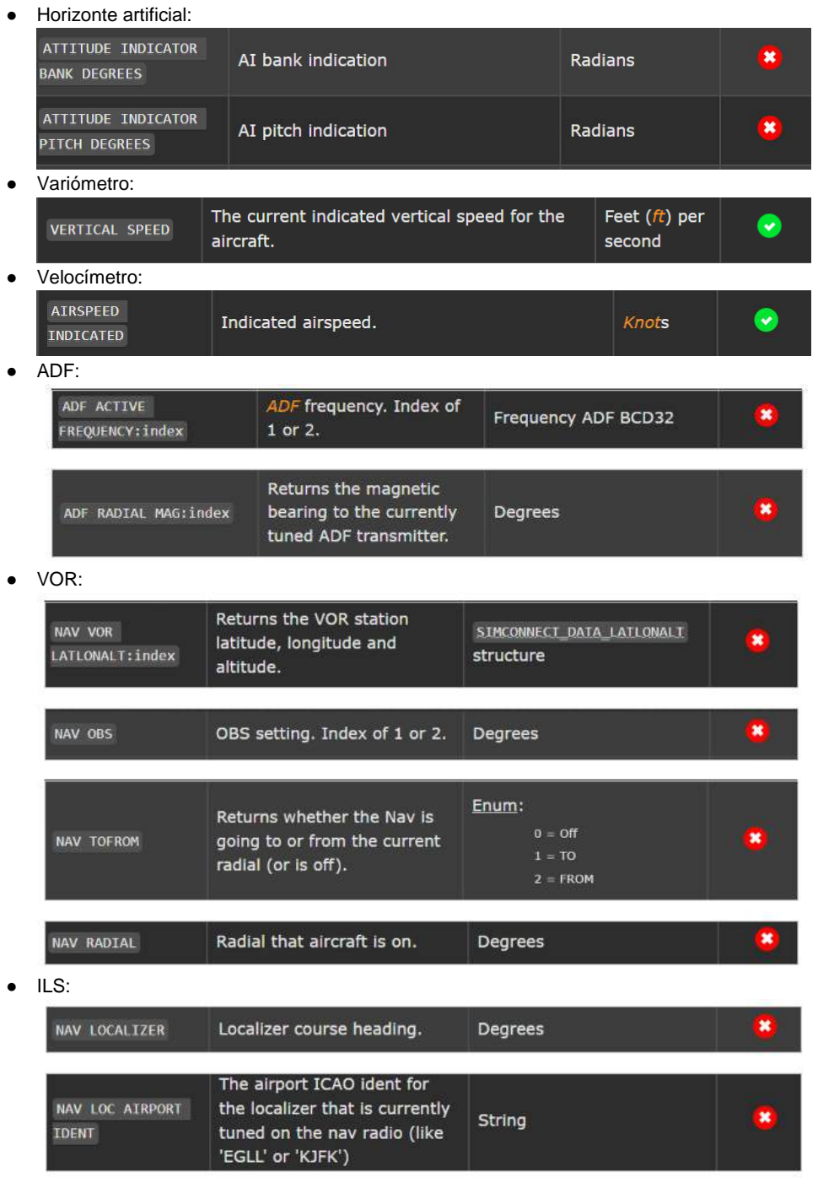
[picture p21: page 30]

- Horizonte artificial:
- Variómetro:
- Velocímetro:
- ADF:
- VOR:
- ILS:

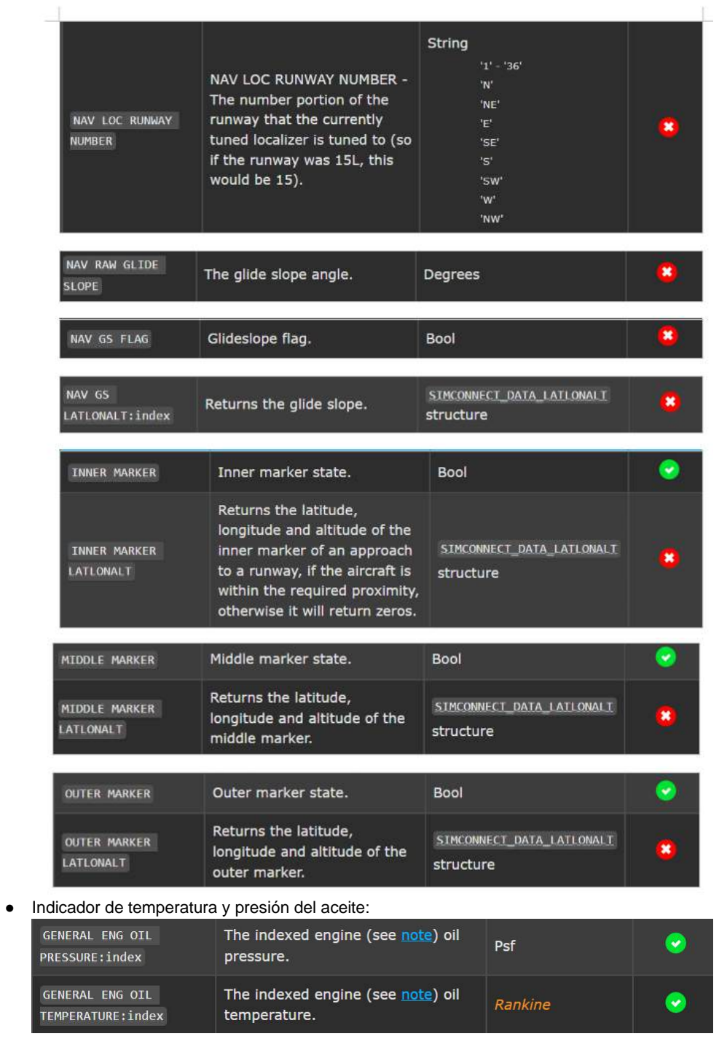
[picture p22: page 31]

- Indicador de temperatura y presión del aceite:

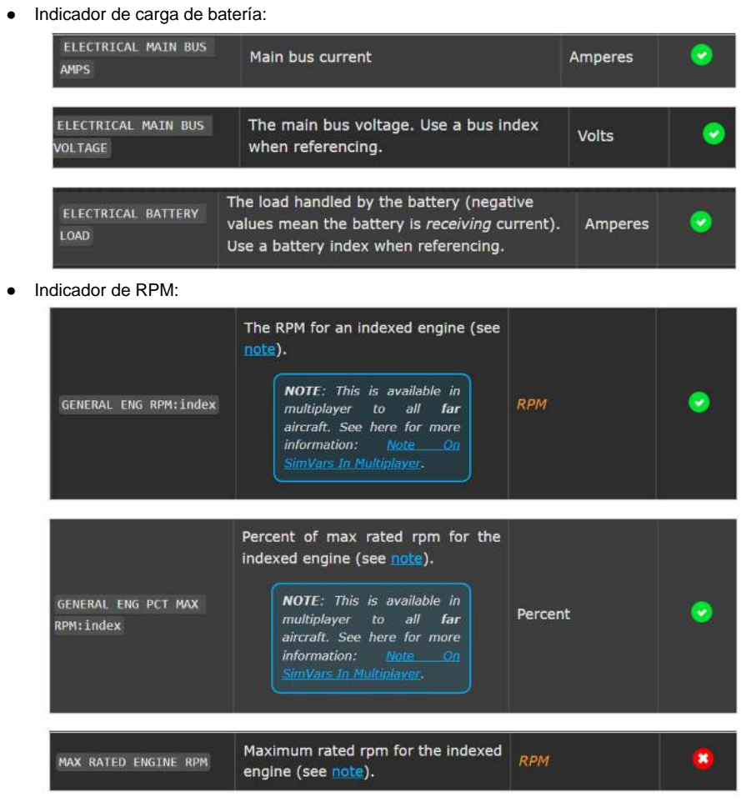
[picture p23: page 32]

- Indicador de carga de batería:
- Indicador de RPM:

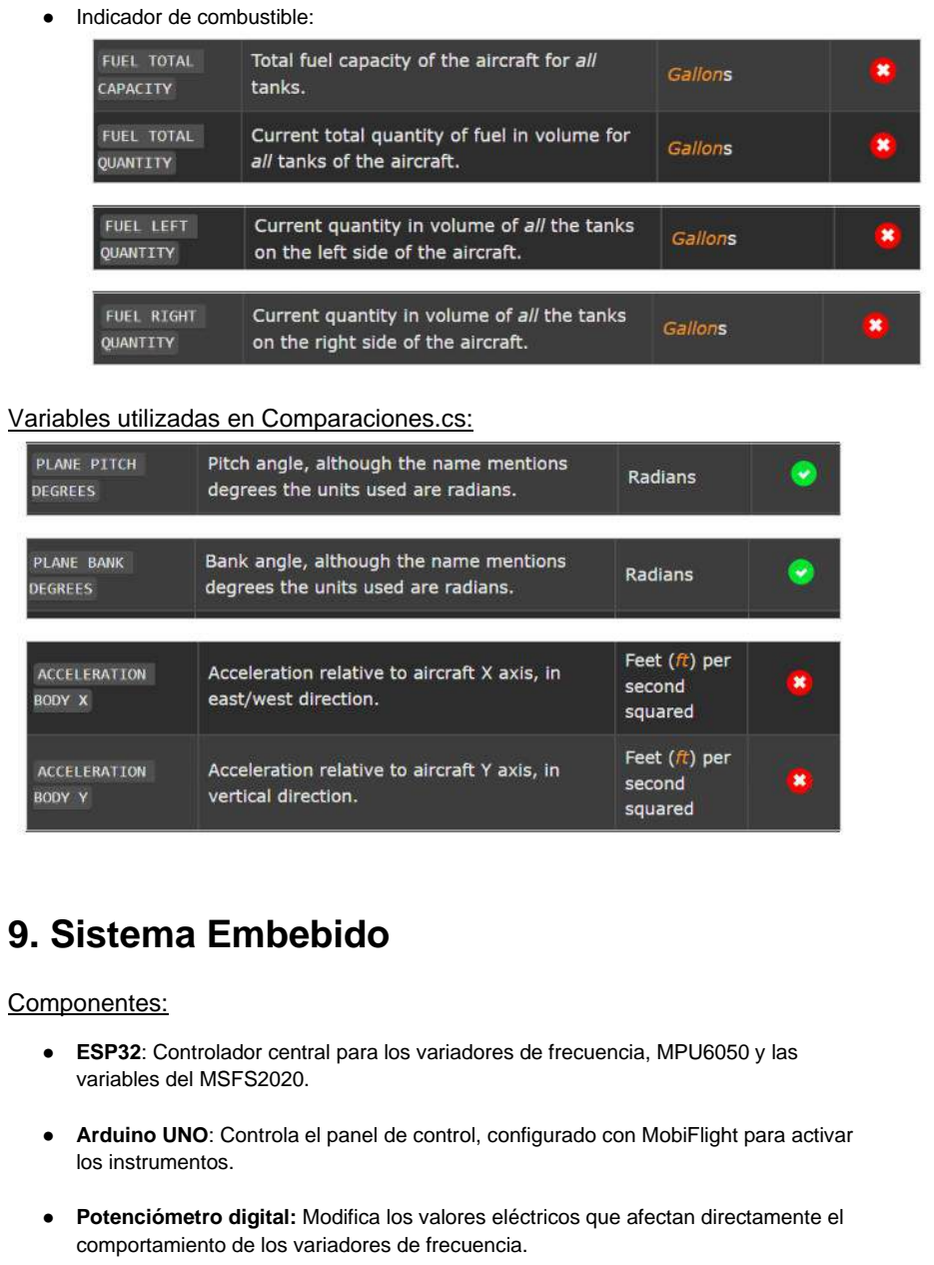
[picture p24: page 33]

- Indicador de combustible:

Variables utilizadas en Comparaciones.cs:

## 9. Sistema Embebido

Componentes:

- ESP32: Controlador central para los variadores de frecuencia, MPU6050 y las variables del MSFS2020.
- Arduino UNO: Controla el panel de control, configurado con MobiFlight para activar los instrumentos.
- Potenciómetro digital: Modifica los valores eléctricos que afectan directamente el comportamiento de los variadores de frecuencia.

Protocolo y Conexiones:

- I2C: Utilizado por el MPU6050 para la detección de movimiento y aceleración.

Configuración de Pines:

- Conexión del MPU6050:
- VCC del MPU6050 a 3.3V del ESP32.
- GND del MPU6050 a GND del ESP32.
- SDA del MPU6050 a GPIO21 del ESP32.
- SCL del MPU6050 a GPIO22 del ESP32.
- Conexión de los Potenciómetros Digitales
a. Para el primer potenciómetro:
- CS_PIN a GPIO15 del ESP32.
- INC_PIN a GPIO14 del ESP32.
- UP_DOWN_PIN a GPIO13 del ESP32.
- VW va al GND del variador 1
- VH y VL van a dos pines del variador 1
- VCC del potenciómetro a la entrada analógica del variador 1 (AI1).
- GND del potenciómetro a GND común del variador 1
b. Para el segundo potenciómetro:
- CS_PIN a GPIO32 del ESP32.
- INC_PIN a GPIO33 del ESP32.
- UP_DOWN_PIN a GPIO25 del ESP32.
- VW va al GND del variador 2
- VH y VL van a dos pines del variador 2
- VCC del potenciómetro a la entrada analógica del variador 2 (AI1).
- GND del potenciómetro a GND común del variador 2.
- Conexión de los optoacopladores y resistencias:
a. Para el primer optoacoplador:
- Anodo del led va a la primera resistencia de 330 Ω y luego al GPIO27 del ESP32
- Catodo del led va a GND del esp32
- Colector va conectado a el puerto x1 del variador 1 y también conectado a la primera resistencia de 10 KΩ y luego va al VCC de la fuente
- Emisor del optocoplador va a COM del variador 1 y también va a GND de la fuente
b. Para el segundo optoacoplador:

- Anodo del led va a la segunda resistencia de 330 Ω y luego al GPIO12 del ESP32
- Catodo del led va a GND del esp32
- Colector va conectado a el puerto x2 del variador 1 y también está conectado a la segunda resistencia de 10 KΩ y luego va al VCC de la fuente
- Emisor del optocoplador va a COM del variador 1 y también va a GND de la fuente
c. Para el tercer optoacoplador:
- Anodo del led va la tercera resistencia de 330 Ω y luego al GPIO18 del ESP32
- Catodo del led va a GND del esp32
- Colector va conectado a el puerto x1 del variador 2 y también está conectado a la tercera resistencia de 10 KΩ y luego va al VCC de la fuente
- Emisor del optocoplador va a COM del variador 2 y también va a GND de la fuente
d. Para el cuarto optoacoplador:
- Anodo del led va la cuarta resistencia de 330 Ω y luego al GPIO19 del ESP32
- Catodo del led va a GND del esp32
- Colector va conectado a el puerto x2 del variador 2 y también está conectado a la cuarta resistencia de 10 KΩ y luego va al VCC de la fuente
- Emisor del optocoplador va a COM del variador 2 y también va a GND de la fuente

## 10. Electrónica

Componentes y Configuraciones:

- Variador de Frecuencia GK500-2T2.2B: Utilizado para controlar los motores a través del protocolo RS485, con una tasa de transferencia de 9600 baudios.
- Arduino UNO: Control del panel de instrumentos.
- MPU6050: Detección de movimiento y orientación para simular los ejes de vuelo.
- Potenciómetro digital: Modifica los valores eléctricos que afectan directamente el comportamiento de los variadores de frecuencia.

Esquemático de Conexiones y Fuente de Alimentación:

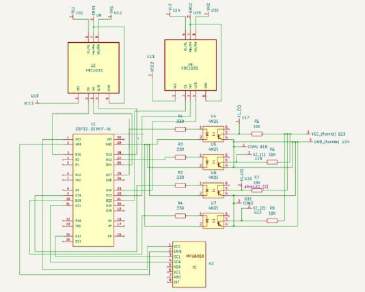
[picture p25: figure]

- Fuente de alimentación separada para el ESP32 y variador de frecuencia, asegurando estabilidad y seguridad en la operación.

PCB:

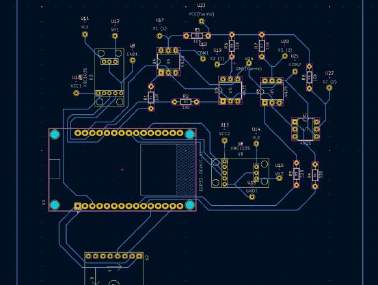
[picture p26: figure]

## 11. Estructura

La estructura de Skylf Flight Simulator, pasó por cambios desde su versión 2019(Avis) hasta la versión que hoy en día nosotros nos hemos dedicado a modificar en la versión 2024(Skylf).
Estos cambios se produjeron por razones, como la implementación de nuevos sistemas de manipulación motora, renovaciones de infraestructura que antes eran inseguras e implementaciones adicionales para distinguir a nuestra versión Skylf.
Anteriormente la cabina contaba con un sistema a 4 soportes por sistema roscado para el soporte de los instrumentos de vuelo, hoy en dia ya es una base fija, soldada directamente a la televisión superior y a la cara posterior del simulador.
El joystick de movimiento, contaba con una base de metal colocada en diagonal al usuario. Actualmente nuestra manera de mover el simulador es mediante un yoke, puesto sobre una base metálica, roscada a la base inferior y soldada al pilar donde se haya el motor dónde predomina el alabeo, dónde se encontraba el anterior stick de control, está colocado (de manera vertical) las palancas del pedestal.

3 de los 4 soportes del anterior panel, fueron removidos completamente, el cuarto soporte fué recortado a la mitad, y se le hizo una estructura a medida para nuestro nuevo panel de control.
Las partes oxidadas fueron removidas y renovadas con pintura negra antioxidante.

## 12. Anexo

Resultados de Investigaciones Hechas:

Variadores de Frecuencia: Los variadores de frecuencia, como el GK500-2T2.2B, permiten controlar la velocidad y es para motores de aplicaciones eléctricas. A través de la comunicación Modbus, se pueden ajustar parámetros en tiempo real, facilitando la implementación de sistemas de control más precisos.

Sensor MPU6050: Este sensor combina un acelerómetro y un giroscopio en un solo chip, permitiendo la captura de datos sobre orientación y movimiento. La utilización de este sensor en el simulador de vuelo ha mostrado ser efectiva para la estabilización y el control dinámico del simulador, proporcionando datos esenciales para la experiencia de vuelo realista.

Fuentes:

https://github.com/brizuu750/SKYLF/tree/main/variadores%20de%20frecuencia/manuales

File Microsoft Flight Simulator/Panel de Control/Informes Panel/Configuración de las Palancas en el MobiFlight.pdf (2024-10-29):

Configuración de las Palancas en el MobiFlight
Paso a Paso de configuración de palancas para vincularlas con MobiFlight y el FS2020

### 1. Conectamos el Arduino UNO al MobiFlight y el FSUIPC7

### 2. Asignamos un Pin del 2 al 13 del Arduino UNO a uno de los terminales de la palanca

(En nuestro caso lo pusimos al pin 8 pero puede ser cualquiera)


### 3. Seleccionar en MobiFlight la pestaña de "MobiFlight Modules"


### 4. Para no tener inconvenientes actualizar el firmware así el MobiFlight detecte

correctamente el la Arduino UNO

### 5. En la barra inferior ir a la pestaña de "Add Device" para agregar un dispositivo que

en nuestro caso es una Palanca.

6. Luego le asignamos a la palanca el nombre con el que queramos que se identifique, siendo en este caso "Tubo Pitot" para la función de la palanca que es sobre el Calentador del Tubo Pitot

### 7. Poner en la "Configuración de Pin" el pin que le asignamos a la palanca (en nuestro

caso el Pin 8 de la Arduino UNO)


### 8. En el Menú principal crear una configuración de entrada en el "Input Configs"

### 9. Para editar la configuración selecciona a la derecha de la fila en "Edit"

### 10. Luego seleccionar los dispositivos conectados al MobiFlight


### 11. Seleccionar en el Action Type el "FSUIPC - Offset" para luego asignarle la acción al

dispositivo que hayamos conectado (en nuestro caso la palanca)


### 12. Dentro de la configuración de entrada se encuentran las configuraciones para

cuando se activa la palanca "On Press" y cuando está del lado contrario "On Release"

### 13. Para la configuración del Offset nos fijamos en el manual de Offset del FSUIPC que

está en internet para buscar la acción de la palanca, y nos dice cuál código de Offset tiene que ir.


### 14. En nuestro caso buscamos el del calentador del tubo pitot. Por lo que ponemos el

que nos dice "029C"

### 15. Para que el Calentador del tubo pitot del Cessna 152 se active en simultáneo a la

palanca que conectamos al FS2020, le asignamos "1" como valor de seteo.


### 16. En "On Release" de igual forma poner el mismo código de Offet pero que cuando

se baje la palanca que el calentador se apague ponemos "0" como valor de seteo


### 17. Luego de esto al probar la palanca que vinculamos a dispositivo que sea (en

nuestro caso el calentador del tubo pitot), se tendría que activar simultáneamente

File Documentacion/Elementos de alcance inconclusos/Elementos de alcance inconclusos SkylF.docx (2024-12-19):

# Elementos de alcance inconclusos

- Se necesitará otro MPU para que se encargue de detectar el movimiento inicial y que el otro MPU que tenemos se encargue del movimiento de los ejes. Todo esto, implementárselo al código ya hecho.
- Terminar la programación del movimiento Z (Segundo variador de frecuencia)
- Solucionar corto circuito en el variador de frecuencia o conseguir otro nuevo.
- Sistema de emergencia para que al medir movimientos o saltos bruscos en MPU, que vuelva al estado cero inmediatamente
- Hacer o inicializar un tercer eje. Esto implicaría conseguir otro motor y variador de frecuencia para eso, teniendo en cuenta los cambios de peso, programación y conexiones
- Implementación de una muestra personalizada del panel de instrumentos virtual (esto a través de una segunda pantalla) a través de una herramienta llamada Air Manager, pero que por su alto costo no pudimos comprar y utilizar. Aun así, tenemos todos los códigos de las variables del Flight Simulator 2020 para ser utilizados en el Air Manager y que se transmitan los datos de vuelo en tiempo.
- En la comunicación variadores de frecuencia, no pudimos seguir con el Protocolo ModBus. Para este tipo de comunicación (nos comunicamos con GTAKE y nos dijeron que no estaban relacionados con la comunicación del protocolo MODBUS.) se necesita direcciones de registro específicas, datos que no nos proporcionaron los proveedores de GTAKE, por lo cuál no se pudo lograr la comunicación. El código para la comunicación está completo (lo tenemos en nuestro GitHub), por lo que lo único que falta son las direcciones de registro.
- Teníamos planeado usar parlantes en la cabina del simulador, pero decidimos usar auriculares
- Inclusión del Transponder, ya que por temas del reducido espacio que hay en la cabina no pudimos encontrar un espacio para poder adaptarlo adecuadamente.
- En la implementación del Yoke y Pedestal para la simulación de vuelo, un integrante del grupo prestó un Yoke y Pedestal para simular el correcto funcionamiento de nuestro simulador. Crear un Yoke y Pedestal casero, que se adapte a la estructura y las conexiones del simulador de vuelo.
- El parlante NVK-25 necesitará de un amplificador de sonido que potencie la señal de audio ya que el volumen que emite es muy bajo. El más recomendado de conseguir es el siguiente: el TPA3116D2

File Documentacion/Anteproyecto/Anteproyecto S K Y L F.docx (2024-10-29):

# S K Y ⅃ ꟻ

Presentación de anteproyecto

Simulador de Vuelo:

El simulador de vuelo es un proyecto para desarrollar una herramienta de simulación de vuelo avanzada y altamente realista. Esta herramienta estará diseñada para recrear con precisión la experiencia de operar una aeronave, proporcionando una inmersión completa desde una cabina de avión. Integrará todos los instrumentos y controles necesarios para una simulación realista, con el fin de mejorar la formación y el entrenamiento de pilotos, así como facilitar el desarrollo y la prueba de nuevas tecnologías aeronáuticas en un entorno virtual seguro y controlado.

Integrantes:

- Esteban, Lautaro: lautaro esteban
- Romo Cordoba, Emiliano: emiliano romocordoba
- Flores, Leandro: leandro flores
- Rubio, Santiago: Santiago Rubio
- Leiva, Santiago: santiagotomas leiva
- Godoy Baldovino, Marco Jofiel: marco godoybaldovino
- Brizuela, Agustin: agustinlionel brizuela
- Meabrio, Lucas: lucasdavid meabrio

Objetivo del proyecto:

El proyecto se utilizará como un simulador de vuelo destinado a practicar maniobras y replicar las condiciones de vuelo reales dentro de una cabina de simulación. Su propósito principal será facilitar la realización de prácticas didácticas, proporcionando a los usuarios un entorno seguro y controlado para mejorar sus habilidades de vuelo y familiarizarse con diferentes escenarios y situaciones aeronáuticas.

Utilidades de el proyecto:

Este es un simulador de vuelo opera integrando modelos precisos de aeronaves, física de vuelo realista, entornos gráficos detallados y sistemas avanzados para proporcionar una experiencia de vuelo auténtica y educativa, además, agregamos una estructura que simula los movimientos de la aeronave agregando realidad a la simulación. Este tipo de simuladores se utilizan tanto con fines de entrenamiento de pilotos como para el entretenimiento de entusiastas de la aviación.

Descripción del funcionamiento:

El funcionamiento de este simulador debería ser sencillo una vez terminado, lo explico en los pasos que hay que seguir a continuación:

1. Iniciar el simulador de vuelo, elegir la aeronave que prefiera usar, recorrido que quiere hacer y otras configuraciones básicas.
2. Se eligen algunas preferencias más (como seleccionar el tiempo, ajustes de la aeronave, etc) en la interfaz de usuario que se presenta antes de la cabina virtual.
3. Ya realizados los pasos anteriores se transporta al usuario a una cabina virtual de la aeronave previamente seleccionada, donde se encuentran los paneles de control, instrumentos y sistemas de la aeronave, etc.
4. Se realizaría el procedimiento de arranque como encender los motores, ajustar los sistemas de la aeronave y configurar el avión para el vuelo.
5. Una vez preparada la aeronave, se realiza el procedimiento de arranque que sería elevar el tren de aterrizaje y mantener contacto con la torre de control.
6. Durante el vuelo ya se puede hacer distintas cosas como maniobras, ajustar la velocidad, seguir la ruta establecida (que para eso se usan sistemas de navegación), etc. Dependiendo de qué tipo de simulador usemos se podrán hacer más funciones como condiciones meteorológicas dinámicas, fallas de sistemas, simulación de emergencias y escenarios de entrenamiento específicos.
7. Como en el despegue, se tendrán que realizar procedimientos para aterrizar como bajar el tren de aterrizaje y alinearse con la pista.
8. Ver la evaluación del vuelo realizado como el cumplimiento de procedimientos, la precisión de aterrizaje, etc.

Análisis de factibilidad:

Para llevar a cabo este proyecto, es fundamental contar con los componentes necesarios, que incluyen una computadora con suficiente potencia para ejecutar un simulador de vuelo, el software del simulador y herramientas para mejorar la estética del proyecto. Además, se requiere un profundo conocimiento por parte del equipo encargado, que abarca desde la programación y ajuste de los sistemas del simulador de vuelo hasta las habilidades necesarias para el mantenimiento del proyecto en su totalidad.

A lo largo del desarrollo del proyecto, se necesitarán continuamente más componentes y herramientas. Esto implica la adquisición de computadoras personales para trabajar en el código y ajustes del sistema, así como la compra de objetos para mejorar la estética, como instrumentos del simulador de vuelo, pantallas, cables, entre otros. Es importante tener en cuenta que la parte estética del proyecto requiere una atención meticulosa y puede implicar una inversión significativa en diversos materiales y equipos.

División de tareas:

Agustin Brizuela:

se encargará de ayudar en el mantenimiento y la restauración de la estructura, también de las conexiones eléctricas del simulador, las conexiones de los instrumentos de la aeronave con el software, en mejorar el movimiento de la cabina y hacer un seguro de movimiento de los motores y ayudar también en las tareas de mis compañeros.

Lautaro Esteban:

Se encargará de realizar un testeo para verificar que los cables funcionen correctamente y ayudará al mantenimiento de la estructura como lijar y pintar. También trabajará con las conexiones eléctricas y configuración de la cabina del simulador de vuelo, verificando para la seguridad del funcionamiento de aquel, como la colocación y configuración de los dispositivos de vuelo y el agregado de la fuente de energía necesaria para la alimentación del proyecto.

También ayudará en la reconstrucción y mantenimiento de la estructura general para que estéticamente se vea de la mejor manera, cómo reemplazar materiales que no se puedan salvar o agregar movimientos seguros a la cabina para seguridad de la gente que lo use. de igual manera que sus compañeros investigara lo más posible para tener la información necesaria para este proyecto, como la configuración de los componentes, la implementación de la fuente de energía, etc.

Leandro Flores:

Se encargará de ayudar en la restauración de la estructura y de buscar información acerca del funcionamiento y de diferentes modelos de sistema de vuelos, acerca de cómo se identifican y se usan la mayoría de instrumentos que se encuentran en la cabina, con la finalidad de tener que realizar la mayoría de pruebas necesarias en el simulador luego de las modificaciones constantes que se realizarán en el proceso de trabajo tanto en el hardware como del reacondicionado de la estructura dando así lugar al correcto funcionamiento del software siendo verificado por mi y otros integrantes.

Marco Godoy Baldovino:

Se encargará de realizar la investigación del software y otros conocimientos necesarios para la realización del proyecto. Esta investigación conlleva obtener información por medio de profesionales en lo que a la electrónica y aviación refiere, por lo que, ya sea virtual o presencialmente podamos adquirir más conocimientos para poder accionar de forma más efectiva en el proyecto.

También se encargará de la modificación del software, sincronizando la conexión de los cables con todos los instrumentos para la simulación (volante, palanca y demás instrumentos del simulador)

Santiago Leiva:

Se encargará junto a otros integrantes de la instalación ordenada y precisa de todos los componentes eléctricos y analógicos necesarios para el funcionamiento del simulador. Esto incluirá la colocación adecuada de la nueva pantalla y la reconfiguración de los cables existentes para garantizar una conexión óptima y segura.

También ayudará al testeo y optimización de todos los componentes para la verificación de su correcto funcionamiento, de esta manera ayudando también a la modificación y reacondicionamiento del software para que el simulador funcione correctamente.

Lucas Meabrio:

Se encargará tanto de la parte electrónica, como el conseguir todos los componentes electrónicos y verifica las conexiones necesarias. También trabajará en otros aspectos como del mantenimiento y reconstrucción de la estructura general del simulador, como encargarse del pulimento con la lija y la pintura, y reemplazar los materiales que ya no sirven, para así llegar a la mejor imagen de la estructura general, también ayudará a la configuración general de la computadora con los componentes del simulador para que se sincronicen y funcionen de la mejor manera..

Emiliano Romo Cordoba:

Se encargará de la imagen del proyecto, página web y realizando tareas como editar de la manera más profesional posible las imágenes y videos, buscar sponsors y lograr así este proyecto tenga el mayor alcance hacia al publico

También se encargará de la parte estética de la estructura como cualquier soldadura y arreglo necesario para que quede de la mejor manera y lo más seguro posible. Haré trabajos como lijar, pintar, soldar, agregar y reemplazar los caños que sean necesarios para la mejor imagen del proyecto.

Santiago Rubio:

Se encargará de toda la parte electrónica y programática (junto a otros integrantes), como el conseguir todos los componentes electrónicos necesarios, hacer el codigo para que los componentes funcionen correctamente, verificar todas las conexiones necesarias y yo sería el encargado de traer una computadora potente de ser necesario (puede que no sea necesario), para que se muestre en las pantallas el punto de vista del piloto y los instrumentos del avión. También se puede encargar de la carpeta de campo y ayudar con el informe final.

Descripción general de cómo trabajará el equipo:

El propósito de nuestro grupo de trabajo es proporcionar apoyo continuo entre sus miembros para facilitar el progreso del proyecto. Aunque hemos asignado tareas específicas como punto de partida, cada integrante está comprometido a ayudar a sus compañeros en cualquier dificultad que pueda surgir, aprovechando así la colaboración y el intercambio de conocimientos dentro del equipo.

Costo del proyecto:

Presentamos una lista provisional de precios de los componentes, basada en los costos vigentes hasta marzo. Es importante tener en cuenta que estos precios pueden variar dependiendo de la fecha de compra y del proveedor seleccionado. Se recomienda revisar y actualizar estos costos conforme avancemos en el proceso de adquisición de los componentes.

Componentes:

- Cuadrante de aceleración para vuelo y palancas de eje intercambiables, 130.000$ARS.
- Palanca de mandos para vuelo, 190.000$ARS.
- televisor de 32 pulgadas usado, estimado de 100.000$ARS.
- Herramientas de trabajo (lijas, soldador, etc), contamos con la mayoría.
- Cables Macho-Hembra (40 cables) 2700$ARS.
- Cables Macho-Macho (40 cables) 2700$ARS.

Costo total del proyecto:425.400$ARS (la suma de todos los componentes estimados por el momento).

Referencias:

https://articulo.mercadolibre.com.ar/MLA-761300919-saitek-logitech-g-pro-flight-yoke-system-vuelo-hace1click1-_JM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

https://es-la.facebook.com/marketplace/item/1614736129324628/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

https://articulo.mercadolibre.com.ar/MLA-617323244-cables-macho-hembra-40-x-20cm-mh-dupont-arduino-protoboard-_JM

https://articulo.mercadolibre.com.ar/MLA-617323696-cables-macho-macho-40-x-20cm-mm-dupont-arduino-protoboard-_JM

Análisis de costo/beneficio:

Para financiar este proyecto, se destinarán recursos para cubrir los gastos necesarios, como la adquisición de instrumentos para el simulador. No obstante, nos comprometemos a minimizar los costos en la medida de lo posible, aprovechando herramientas proporcionadas por la escuela y buscando contribuciones del grupo de trabajo, así como de personas o empresas interesadas en colaborar a medida que avancemos en el proyecto y demostremos progresos tangibles.

En un esfuerzo por optimizar los recursos, hemos logrado reducir gastos significativos, como la compra de una computadora capaz de ejecutar el simulador. En este momento, los demás costos se distribuirán equitativamente entre los miembros del equipo de trabajo, asegurando una gestión financiera responsable y colaborativa.

Diagrama en bloques del prototipo:


Diagrama de tiempo de desarrollo:


Escuela de Educación Técnica Nº7 Taller Regional Quilmes Prácticas Profesionalizantes: Especialidad Aviónica

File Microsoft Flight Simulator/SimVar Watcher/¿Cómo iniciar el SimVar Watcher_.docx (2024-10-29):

# ¿Cómo iniciar el SimVar Watcher?

Esto es una forma de hacerlo utilizando Visual Studio Code (mínimo 2017) que muestra cómo conectarse a Microsoft Flight Simulator desde una aplicación de C# para recuperar los SimVars.

- Descarga el proyecto SimVarWatcher desde este repositorio en github: billtt/SimvarWatcher: Microsoft Flight Simulator 2020 SimConnect sample project (github.com) (https://github.com/billtt/SimvarWatcher)
- Para cargar el proyecto en Visual Studio, simplemente haga doble clic en el archivo de la carpeta de ejemplo, llamada “Simvars.csproj”. Una vez abierto en VS, vaya al menú “Build” y seleccione “Build Solution” para compilar el archivo.


- Una vez que se ha compilado el proyecto, se puede ejecutar haciendo clic en el botón Inicio en Visual Studio. Esto abrirá la aplicación Simvar Watcher:


- Lo primero que hay que hacer es conectar la aplicación a la simulación, lo que requiere que Microsoft Flight Simulator se esté ejecutando (si no es así, inícialo ahora antes de continuar). Debe iniciar una misión para que la aplicación pueda recuperar y configurar los SimVars que desee, y luego, en la aplicación Simvar Watcher, haga clic en el botón “Connect” en la parte superior izquierda de la ventana. El indicador rojo ahora debería convertirse en un verde/azul parpadeante para indicar que la aplicación se ha conectado correctamente a la simulación:
- Tenga en cuenta que la luz parpadea entre azul y verde en función de la frecuencia de actualización, que puede configurar con el control deslizante Frecuencia junto al botón “Connect/Disconnect”.

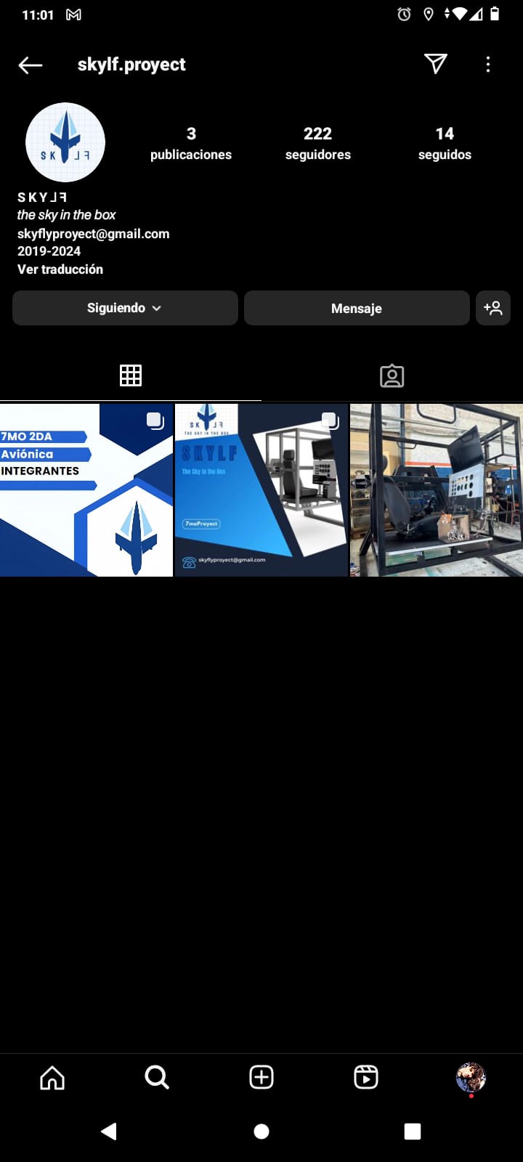
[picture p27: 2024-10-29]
Diseño de marca/Instagram/red social.jpg

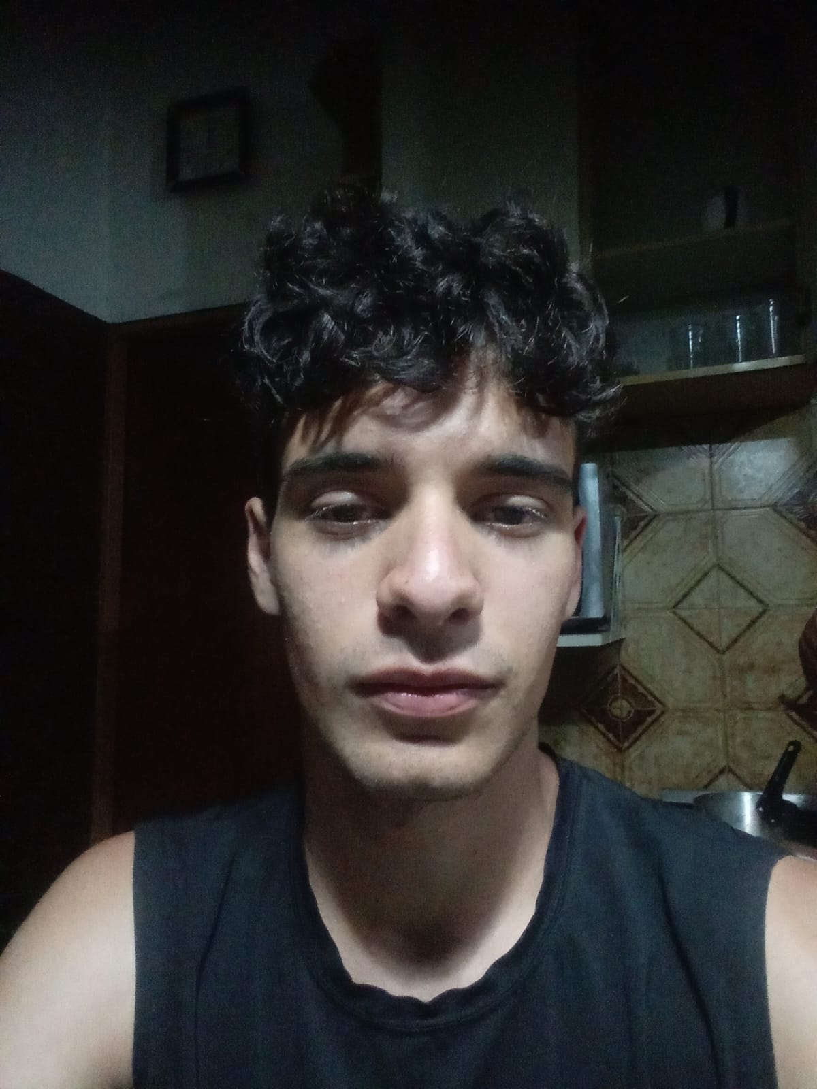
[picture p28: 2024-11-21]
Pagina web/images/romocordoba.jpg

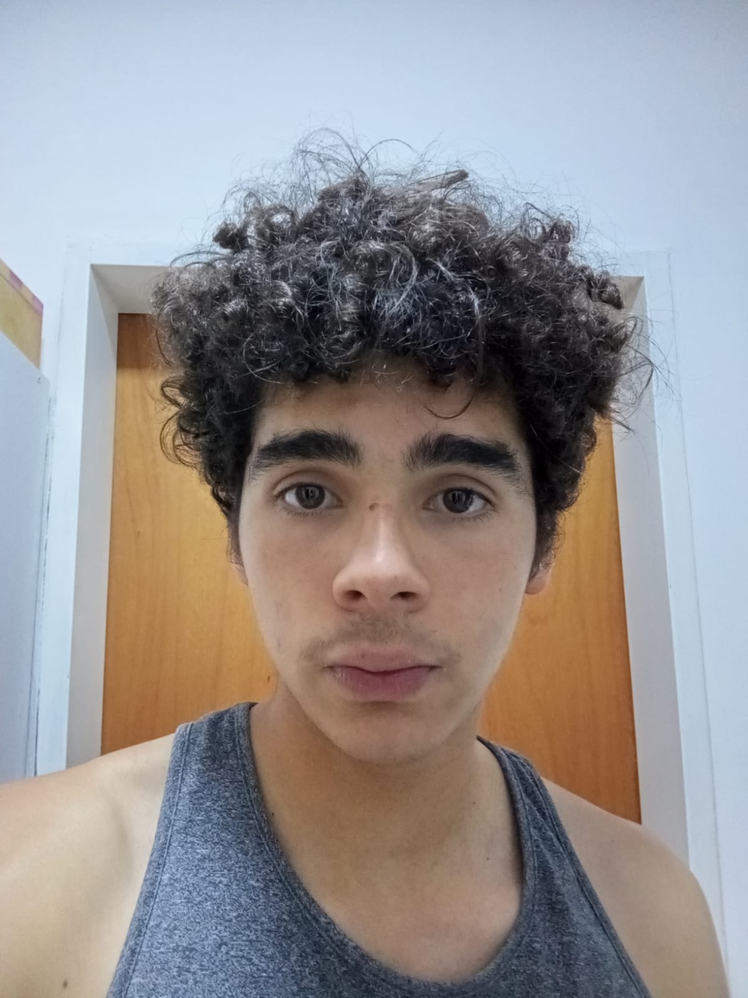
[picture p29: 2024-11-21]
Pagina web/images/meabrio.jpg

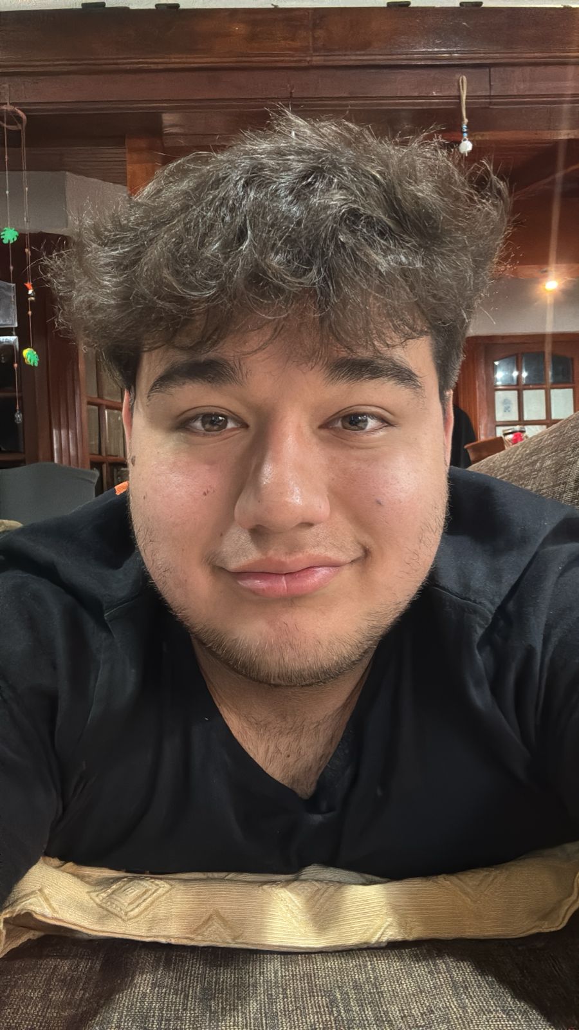
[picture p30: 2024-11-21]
Pagina web/images/brizuela.jpg

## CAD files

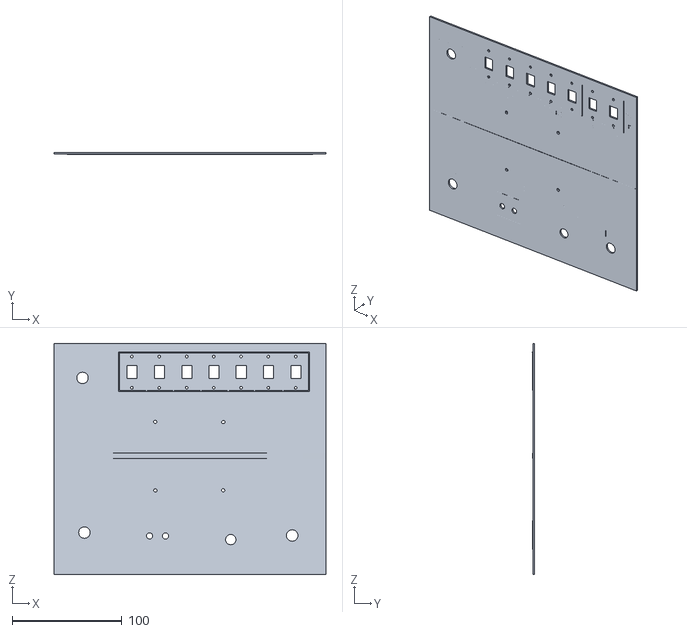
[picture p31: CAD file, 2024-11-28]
Microsoft Flight Simulator/Panel de Control/Modelos 3D del Panel de Control/Panel Cessna152 sin logo.stl
248.0 x 2.25 x 211.0

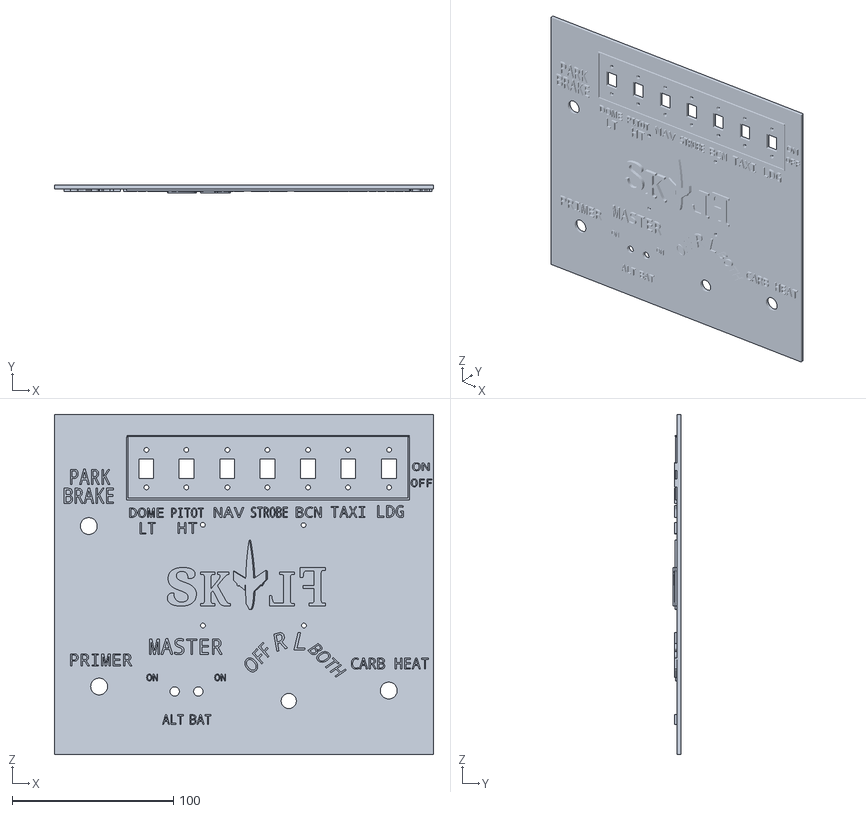
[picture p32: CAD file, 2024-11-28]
Microsoft Flight Simulator/Panel de Control/Modelos 3D del Panel de Control/PanelDeControlCessna152 SkylF con logo.stl
235.0 x 5.05 x 211.0

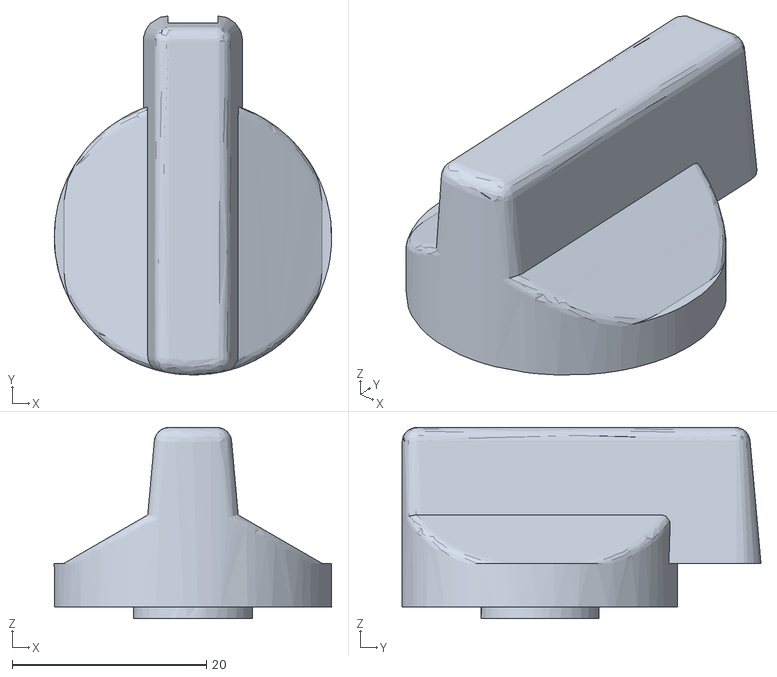
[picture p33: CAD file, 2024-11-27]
Microsoft Flight Simulator/Panel de Control/Modelos 3D del Panel de Control/Perilla 3D para Magneto.stl
28.6 x 37.0 x 19.7

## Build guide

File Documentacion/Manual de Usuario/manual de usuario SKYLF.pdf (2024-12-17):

# MANUAL

DE

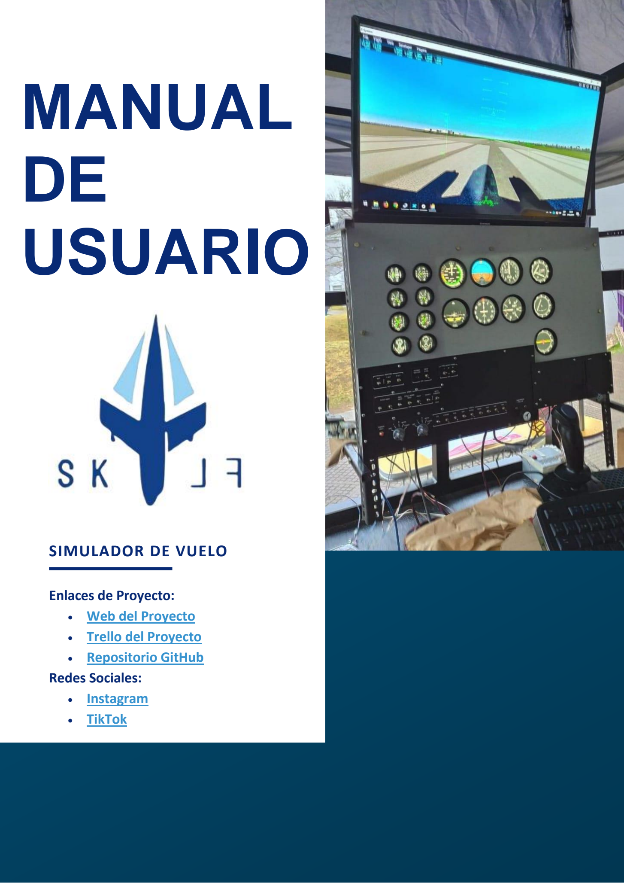
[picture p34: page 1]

1

### SIMULADOR DE VUELO

Enlaces de Proyecto:
- Web del Proyecto (https://estebanlautaro.github.io/Paginaweb-SKYFLY/)
- Trello del Proyecto (https://trello.com/b/u9Dn0bU8/kanban)
- Repositorio GitHub (https://github.com/brizuu750/SKYLF)
Redes Sociales:
- Instagram (https://www.instagram.com/skylf.proyect/)
- TikTok (https://www.tiktok.com/@skyfly826?_t=8qnCGQhRKsA&_r=1)

# USUARIO

2

# Índice general del manual

## 1. Introducción

### 1.1 Descripcion general 1.2 Objetivos 1.3 Destino y alcance

## 2. Componenetes del sistema

### 2.1 Pantallas 2.2 Panel de instrumentos 2.3 Pedestal de mando 2.4 Yoke (sistema de control) 2.5 Sistemas de movimiento

## 3. Guia de uso

### 3.1 Flight simulator 3.2 Panel de control 3.3 Lectura y Utilización de Instrumentos en Pantalla 3.4 Ejecución de Maniobras Básicas de Vuelo

## 4. Precauciones de seguridad

### 4.1 Antes de operar 4.2 Durante la operacion

## 5. Instalacion y configuracion

### 5.1 Instalación y Configuración de Software 5.2 Configuración del Sistema de Comunicación 5.3 Configuración de MobiFlight para el Control de Paneles 5.4 Pruebas y Ajustes Iniciales

## 6. Contacto

3

## 1. Introducción

### 1.1 Descripcion general

El simulador de vuelo SKYLF 2024 es una plataforma basada en la cabina de un Cessna 152, diseñada para simular las maniobras y controles reales de una aeronave. Combina un sistema físico interactivo con software de simulación y tecnología de control de movimiento.

### 1.2 Objetivos

Objetivo general:Ofrecer una experiencia inmersiva que permita simular el control de un avión real mediante un sistema físico conectado al simulador virtual.
Objetivos específicos:
Integrar controles físicos (interruptores, botones y palancas) con un sistema digital.
Controlar movimientos Pitch y Roll mediante motores trifásicos sincronizados con el simulador virtual.

### 1.3 Destino y alcance

Este simulador está destinado a estudiantes de ingeniería, entusiastas de la aviación y centros de enseñanza técnica que busquen herramientas de formación práctica en sistemas de control, mecánica de vuelo y electrónica aplicada.

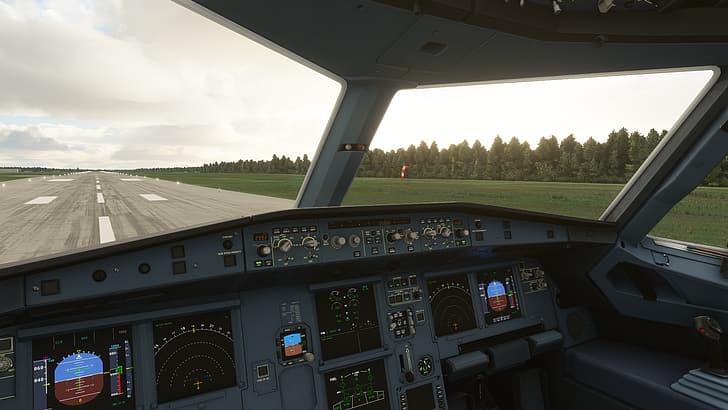
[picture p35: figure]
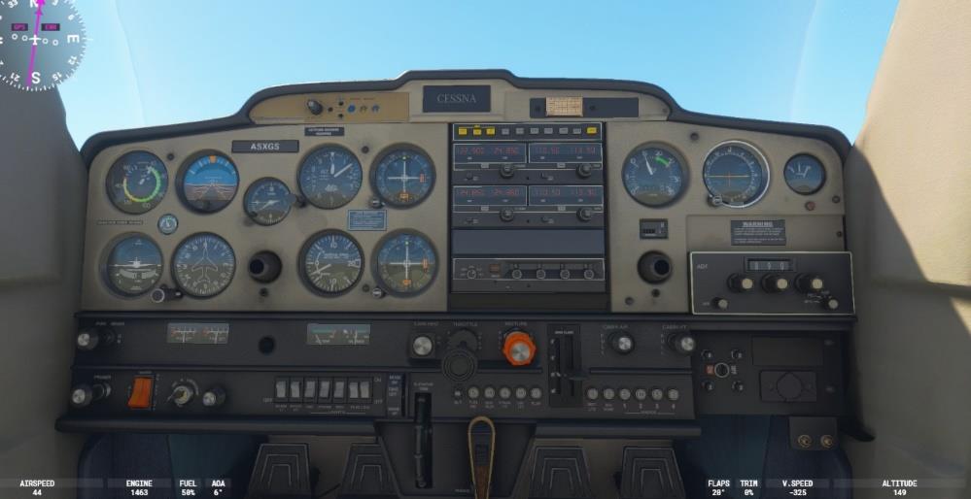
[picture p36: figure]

4

## 2. Componenetes del sistema

### 2.1 Pantallas

Pantalla de 32” superior para la simulación de vuelo.

Pantalla de 32” secundaria para instrumentos.

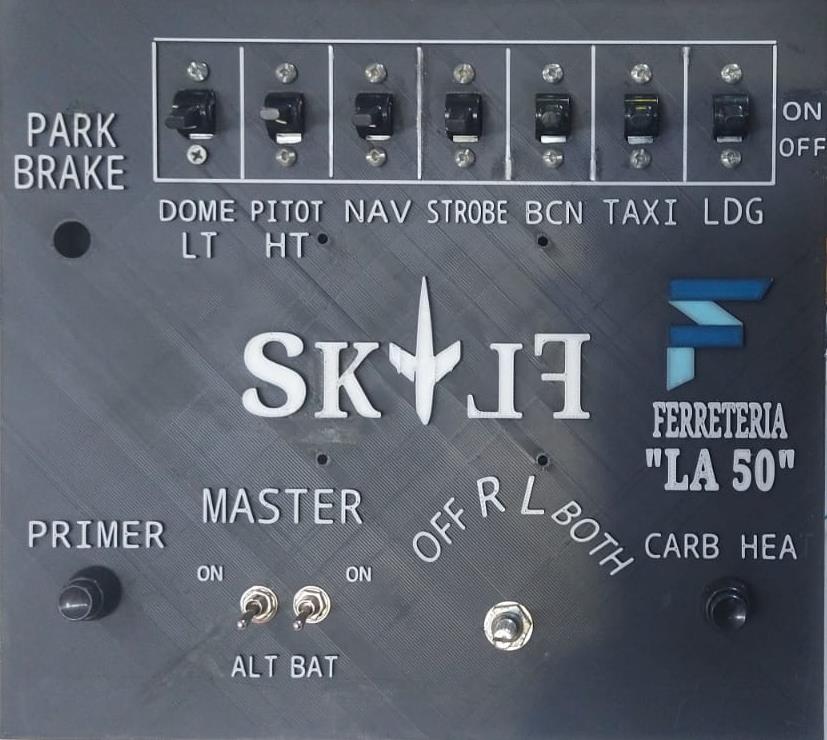
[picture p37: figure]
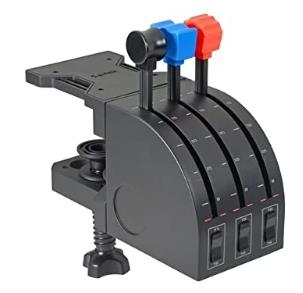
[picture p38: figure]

5

### 2.2 Panel de instrumentos

- Interruptores para sistemas de luces (NAV, BCN, TAXI, LAND).
- Selector de magnetos (OFF, L, R, BOTH).
- Freno de parqueo (PARK BRAKE).
- Controles de calentador del tubo Pitot y bomba de combustible.

### 2.3 Pedestal de mando

- Palancas:
Acelerador: Control de potencia del motor.

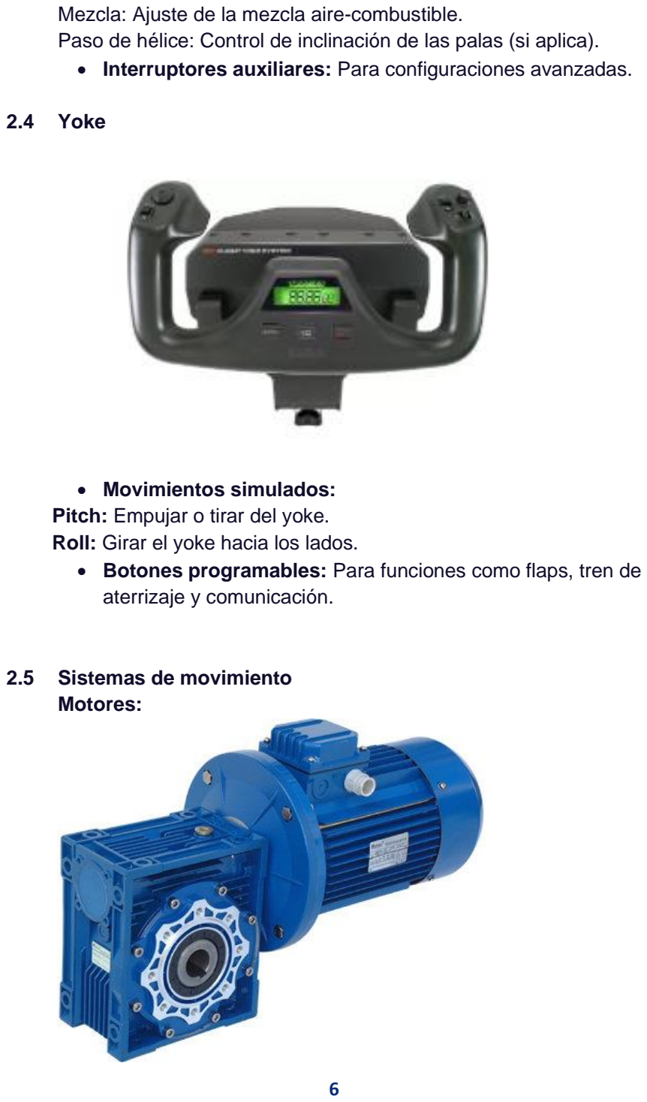
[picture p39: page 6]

6

Mezcla: Ajuste de la mezcla aire-combustible.
Paso de hélice: Control de inclinación de las palas (si aplica).
- Interruptores auxiliares: Para configuraciones avanzadas.

### 2.4 Yoke

- Movimientos simulados:
Pitch: Empujar o tirar del yoke.
Roll: Girar el yoke hacia los lados.
- Botones programables: Para funciones como flaps, tren de aterrizaje y comunicación.

### 2.5 Sistemas de movimiento

Motores:

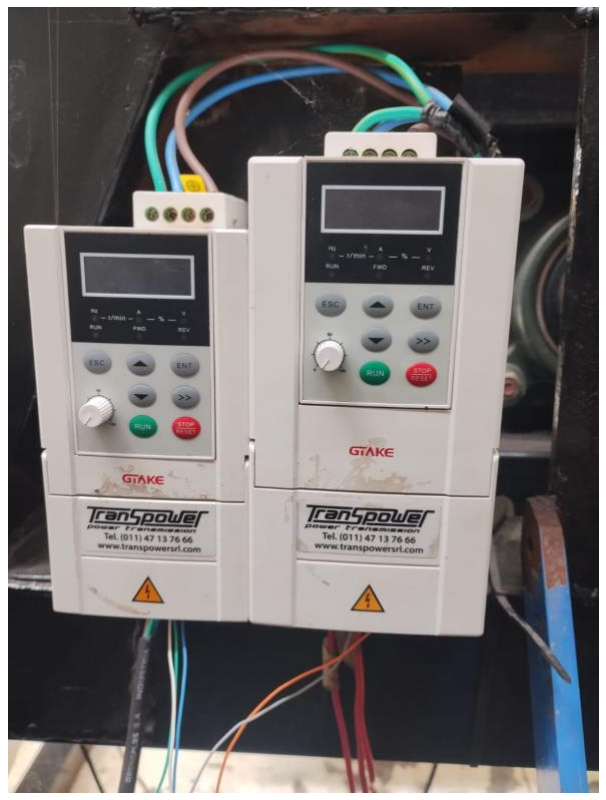
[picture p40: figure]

7

Sensores:
MPU6050 para detectar inclinación y sincronizar movimientos físicos con el simulador virtual.

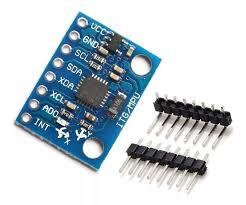
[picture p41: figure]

Controladores:

ESP32 y potenciómetros digitales para ajustar la resistencia y velocidad de los motores.

8

## 3. Guia de uso

### 3.1 Procedimientos de Encendido y Apagado

Encendido del Simulador:
1) Verificar Conexiones: Antes de encender el simulador, asegúrese de que todas las conexiones de hardware estén correctamente instaladas y que no haya cables sueltos o dañados.
2) Iniciar el Software:
- Abra Microsoft Flight Simulator 2020 en la computadora.
- Ejecute los programas auxiliares, como MobiFlight y FSUIPC7, necesarios para la sincronización entre los controles físicos y el simulador.
3) Encender el Panel de Control: Active los interruptores principales del panel de control físico (asegurándose de seguir el orden correcto, de ser necesario).
4) Calibración Inicial de Sensores y Controladores: Espere a que el sistema complete su auto-calibración. Esto permite que el sensor MPU6050 y los motores controlados por el ESP32 ajusten sus parámetros iniciales.

Apagado del Simulador:

1) Cerrar el Software: Primero, cierre Microsoft Flight Simulator 2020, y luego desactive FSUIPC7 y MobiFlight.
2) Desactivar el Panel de Control: Apague los interruptores del panel de control y desconecte la alimentación eléctrica.
3) Inspección de Seguridad: Verifique que no haya sobrecalentamiento en los componentes y que todos los sistemas se hayan apagado correctamente.

### 3.2 Uso del Panel de Control

El panel de control físico del simulador replica las funciones básicas de una cabina de avión real, permitiendo a los usuarios gestionar sistemas de vuelo como la iluminación, la bomba de combustible, los magnetos, entre otros. A continuación, se describen los controles y su operación:

9

- Interruptores de Iluminación (BCN, LAND, TAXI, NAV, STRB): Activa y desactiva las luces de navegación, aterrizaje, y otras luces exteriores. Esto se puede hacer en cualquier momento del vuelo, según sea necesario.
- Llave de Magnetos: Este interruptor rotativo permite seleccionar entre diferentes posiciones de encendido, simulando el sistema de encendido de los magnetos, que distribuyen corriente eléctrica al motor.
- Primer: Inyecta combustible en los cilindros del motor antes de arrancarlo, una función especialmente útil en condiciones de baja temperatura.

Consejo de Seguridad: Realice una inspección visual del panel de control antes de activar cualquier sistema y asegúrese de que todos los interruptores estén en la posición "OFF" antes de encender el simulador.

### 3.3 Lectura y Utilización de Instrumentos en Pantalla

El simulador incluye una pantalla de 32 pulgadas que muestra datos en tiempo real de los instrumentos de vuelo, tales como altímetro, velocímetro y horizonte artificial. Estos instrumentos están sincronizados con Microsoft Flight Simulator 2020 y reflejan la situación actual del vuelo.
Principales Instrumentos en Pantalla:
- Altímetro: Indica la altura sobre el nivel del mar. Es crucial monitorizar esta lectura especialmente durante ascensos y descensos.
- Velocímetro: Muestra la velocidad de vuelo en nudos. La velocidad debe mantenerse en rangos seguros, evitando velocidades críticas para prevenir posibles “stall” o pérdida de sustentación.
- Horizonte Artificial: Permite visualizar la orientación del avión en relación al horizonte, mostrando los ángulos de cabeceo y alabeo.
- Variómetro: Muestra la velocidad de ascenso o descenso del avión, ayudando a los usuarios a ajustar la altitud con precisión.

Consejo de Seguridad: Familiarícese con cada instrumento antes de realizar maniobras avanzadas. Asegúrese de entender el propósito de cada uno y cómo afectan el estado y control de la aeronave.

10

## 4. Precauciones de seguridad

### 4.1 Antes de operar

1) Inspección inicial:
- Verificar que todas las conexiones eléctricas estén firmes y correctamente aisladas.
- Asegurarse de que no haya cables pelados, expuestos o en mal estado.
- Revisar que la estructura metálica esté completamente fija al suelo para evitar movimientos inesperados durante la operación.
2) Zona de operación:
- Operar el simulador en un lugar seco y ventilado.
- Mantener el área libre de líquidos que puedan derramarse sobre los componentes electrónicos.
- Asegurarse de que no haya objetos sueltos cerca de los motores, cables o estructuras que puedan interferir en su funcionamiento.
3) Estado del operador:
1. Solo personas capacitadas o con conocimiento básico del sistema deben operar el simulador.
2. El operador debe usar calzado cerrado y seco para evitar descargas eléctricas.
3. Evitar operar el simulador si se siente fatigado, mareado o bajo efectos de medicamentos que afecten la concentración.

### 4.2 Durante la operación

1) Interacción con los controles:
- Utilizar los interruptores, botones y palancas con suavidad para evitar daños mecánicos.
- No ejercer fuerza excesiva en el yoke, pedestal o panel de instrumentos.
2) Movimientos del simulador:
- Asegurarse de que las extremidades del operador y las de los observadores estén alejadas de las partes móviles (por ejemplo, áreas donde los motores generan movimientos Pitch y Roll).
- Evitar que niños o personas no capacitadas se acerquen a las áreas móviles mientras el simulador está en funcionamiento.
3) Monitoreo del sistema:

11

- Prestar atención a ruidos inusuales provenientes de los motores o variadores de frecuencia. Si se detecta un ruido anormal, detener el simulador inmediatamente y realizar una inspección.
- Si alguna de las pantallas deja de funcionar o muestra información errónea, pausar la operación y verificar las conexiones.
4) Comportamiento ante fallos:
- En caso de un corte de energía, apagar todos los interruptores del panel y desconectar el sistema para evitar sobrecargas al reanudar la corriente.
- Si el simulador no responde a los controles, detener la operación y revisar las conexiones del ESP32, los motores y el panel.

## 5. Instalacion y configuracion

### 5.1 Instalación y Configuración de Software

Incluye la instalación de MobiFlight, FSUIPC7 y SimConnect, así como su configuración para conectar el hardware con el simulador.

### 5.2 Configuración del Sistema de Comunicación

Guía para configurar el potenciometro y los pines de comunicación del ESP32 y el variador de frecuencia.

### 5.3 Configuración de MobiFlight para el Control de Paneles

Paso a paso para mapear los controles físicos en MobiFlight y asignar sus funciones en Flight Simulator 2020.

### 5.4 Pruebas y Ajustes Iniciales

Procedimientos para probar y ajustar el funcionamiento de cada componente antes de la operación completa

## 6. Contacto

- Página web del proyecto: https://estebanlautaro.github.io/Paginaweb-SKYFLY/
- Redes sociales:
Instagram: @skylf.proyect
TikTok: @skyfly826

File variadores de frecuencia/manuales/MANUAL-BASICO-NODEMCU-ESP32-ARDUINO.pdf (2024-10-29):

1

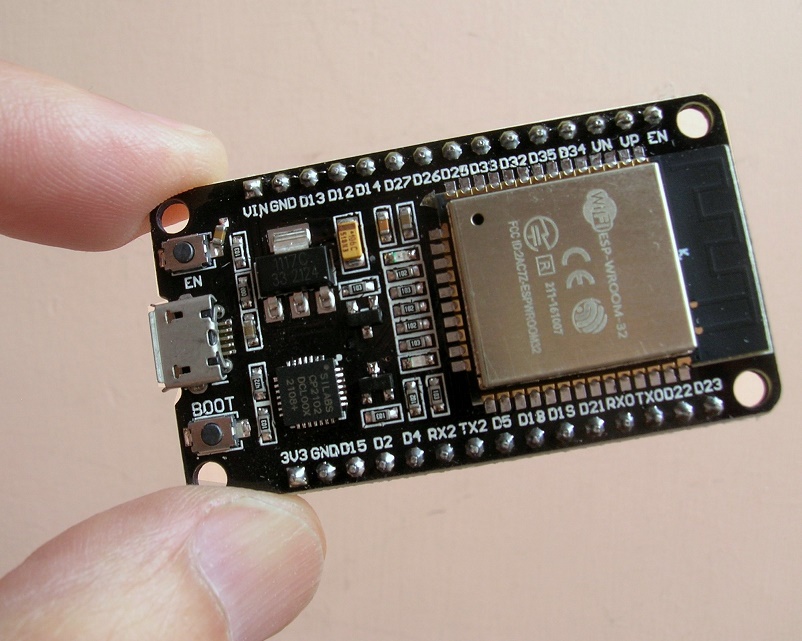
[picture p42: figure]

Manual básico NodeMCU ESP32 DevKit V1 Arduino IDE. Punto Flotante S.A. 2022

## Manual básico de pruebas del NodeMCU

versión ESP32 DevKit V1. Arduino IDE.

Contenido:

### 1. Introducción al NodeMCU, ESP32 DevKit V1

2. Conexión del dispositivo.
3. Bajar a su computadora el IDE Arduino.
4. Integrar (Add On) al IDE el módulo NodeMCU ESP32.
5. Carga del driver CP2102 USB-Serial.
6. Carga de un programa de aplicación simple.

2

### 1. Introducción al NodeMCU versión ESP32:

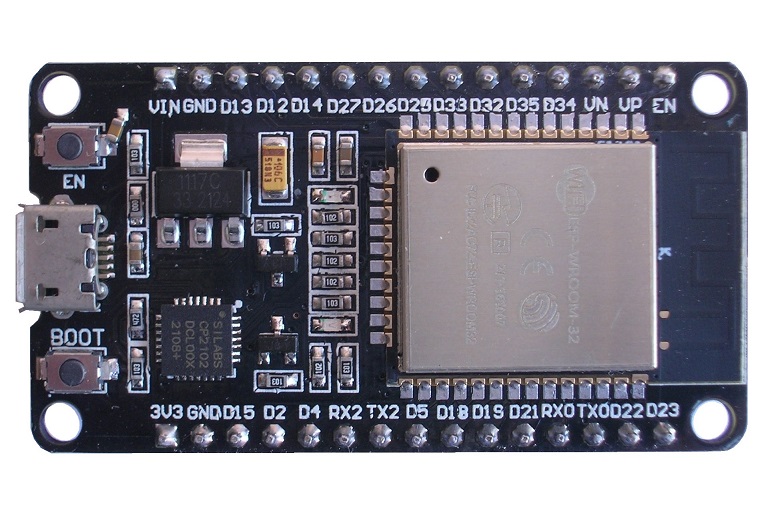
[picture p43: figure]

Figura 1

Un dispositivo microcontrolador nuevo ha ingresado al mundo de la electrónica, bajando los costos de sistemas que antes eran complejos en su desarrollo, como el llamado IoT (Internet of Things) y la automatización de casas (Home Automation). Se trata del nuevo NodeMCU en su versión ESP32.

Descripción general:

El NodeMCU ESP32 es una plataforma completa de desarrollo, módulo SoC (system on chip), basado en el microcontrolador Tensílica de 32 bits, funcionando a una frecuencia de reloj de 240 Mhz, con una memoria Flash de 4MB, y 500 KB de SRAM. Tiene conectividad inalámbrica Wifi, estándar 802.11 b/g/n, y Bluetooth integrado BLE.

3

NodeMCU ESP32 mejora las capacidades del ESP8266, con un procesador de doble núcleo de 32 bits. Además incluye internamente una gran cantidad de periféricos para la conexión con sensores táctiles capacitivos, sensor de efecto Hall, amplificadores de bajo ruido, interfaz para tarjeta SD, Ethernet, SPI de alta velocidad, UART, I2S e I2C.

El ESP32 tiene el protocolo TCP-IP integrado, permitiendo su acceso a internet a través de un router Wifi, con el cual puede conectarse a una distancia de 3 a 5 metros en forma inalámbrica, gracias a su antena integrada al módulo.

Sus aplicaciones típicas se encuentran en el llamado ‘Internet of Things’, IoT, es decir, la supervisión y el control remoto de dispositivos ya sea a través de una red local, LAN ó remotamente operando como servidores de internet (web server), para funciones de robótica y domótica.

NodeMCU ESP32 integra una interfaz USB-Serial CP2102 y, durante la fase de desarrollo de aplicaciones, puede operarse desde el puerto USB de la computadora con un cable micro USB, el cual permite la comunicación serial a una velocidad de 9600 hasta 921,600 bps, y proporciona además la alimentación de 5v al módulo.

El módulo ESP32 cuenta con 30 pines, de los cuales 25 son de los llamados GPIO (General Purpose Input Output). Puede funcionar de manera totalmente autónoma como servidor web y recibir comandos remotos para operar los pines mencionados, ya sea para activar dispositivos ó enviar status de sensores digitales ó analógicos. Incluye también pines con las funciones PWM, 1wire, I2C, SPI, UART, y convertidores A/D de 12 bits.

Su voltaje de alimentación es de 5v, el cual es reducido a 3.3v por medio de un regulador on board. El consumo promedio es de 100 ma. La corriente aumenta durante la trasmisión y recepción WiFi, de tal manera que, si se alimenta con fuente externa, se recomienda una capacidad de 300 ma. También puede alimentarse directamente a través del conector micro USB.

Los lenguajes de programación más usados para NodeMCU ESP32, son Arduino y MicroPython. Ambos son de código abierto y cuentan con herramientas de desarrollo gratuitas.

4

Especificaciones:
- Placa: ESP32 DEVKIT V1 (Espressif)
- SoM (System on module): ESP-WROOM-32 (Espressif)
- SoC (System on chip): ESP32 (ESP32-D0WDQ6)
- Procesador: Tensilica Xtensa Dual-Core 32-bit LX6.
- Frecuencia del reloj: 160 a 240 Mhz.
- Desempeño: Hasta 600 DMIPS
- Memoria:
448 KByte ROM
520 KByte SRAM

### 16 KByte SRAM in RTC (Real Time Clock)

QSPI Flash/SRAM, 4 MBytes
- Número total de pines GPIO: 25
- WiFi con antena integrada: estándar 802.11 b/g/n. Velocidad de 150.0 Mbps
- Bluetooth: BLE (Bluetooth Low Energy) y Bluetooth Classic
- Interfaz USB-Serial CP2102 on board.
- Modo de funcionamiento Low Power.
- Peripheral Input/Output (25 pines GPIO)
- ADCs (Convertidores Analógico Digital) de 12 bits
- DACs (Convertidores Digital Analógico) de 8 bits
- I²C (Inter-Integrated Circuit)
- UART (Universal Asynchronous Receiver/Transmitter)
- SPI (Serial Peripheral Interface)
- I²S (Integrated Interchip Sound)
- RMII (Reduced Media-Independent Interface)
- PWM (Pulse-Width Modulation).
- Regulador de 3.3 volts on board.
- Voltaje de Alimentación (USB): 5V DC
- Niveles de voltaje de entradas/salidas: 3.3v CD
- Dimensiones: 51.5 mm x 28.3 mm x 12 mm
- Distancia entre pines: estándar 2.54 mm
- Distancia entre ambas filas de pines: 26.0 mm
- Número total de pines: 30

5

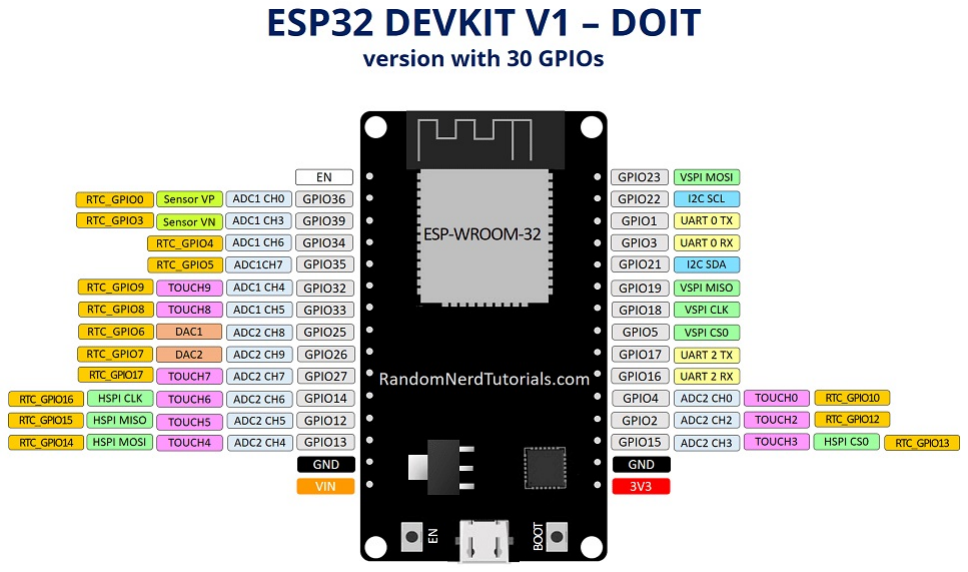
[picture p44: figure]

Figura 2

### 2. Conexión de componentes:

Para la realización de la instalación del software Arduino IDE, y las primeras pruebas al módulo, usted necesita:

- 1 módulo NodeMCU versión ESP32
- 1 cable Micro USB, a través del cual se le da la alimentación de 5v al NodeMCU y al mismo tiempo puede tener comunicación con la PC (Figura 3)

6

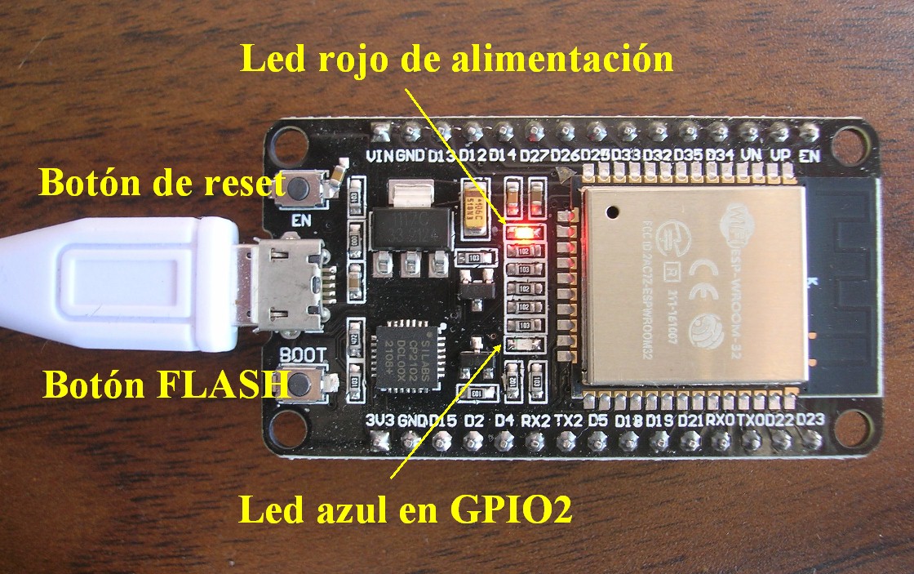
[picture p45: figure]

Figura 3

Inserte el cable Micro USB al NodeMCU, con lo cual alimentará el circuito. Debe encenderse el led rojo de alimentación.

### 3. Bajar a su computadora el IDE Arduino:

Es importante que usted cuente con la versión más reciente del IDE, ya que éste se está constantemente actualizando con nuevas librerías y placas de desarrollo. En este caso nuestra placa es la NodeMCU versión ESP32. El link es el siguiente:

arduino.cc/en/Main/Software

Almacene en una carpeta el programa de instalación (Figura 4):

7

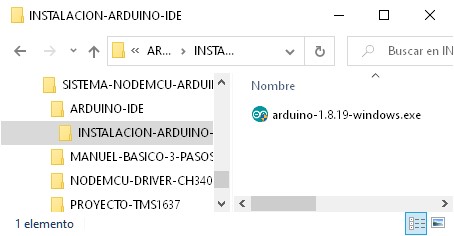
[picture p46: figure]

Figura 4

Ejecute el archivo de instalación. Al finalizar, usted tendrá la carpeta de instalación completa (mostrada en la figura 5) en el path:

C:\Program Files (x86)\Arduino

La carpeta default para almacenar sus nuevos proyectos estarán en el path: C:\Users\JBM\Documents\Arduino

En donde “JBM” corresponde en este ejemplo al nombre del usuario.

Adicionalmente, habrá un ícono del IDE Arduino en el escritorio de su PC.

8

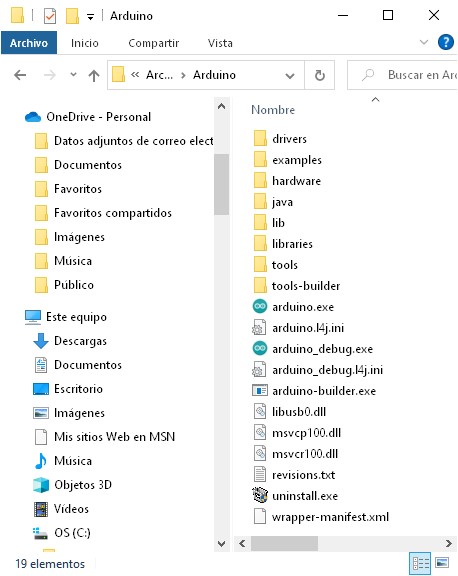
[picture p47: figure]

Figura 5

4. Integrar (Add On) al IDE el sistema ESP32 Devkit V1.

El IDE de Arduino permite integrar numerosas placas nuevas de desarrollo, en este caso es necesario añadir la que usaremos en este manual.

Abra el IDE desde su escritorio y elija la opción “Archivo” y “Preferencias” (figura 6)

9

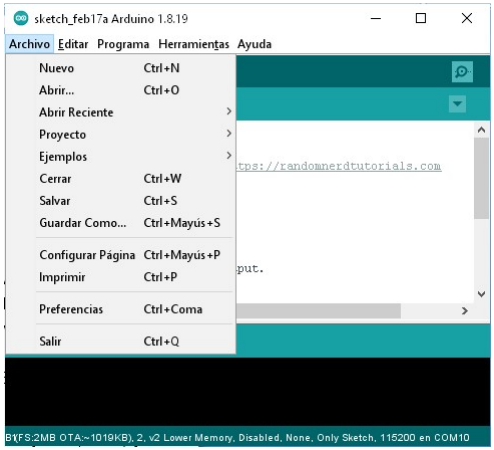
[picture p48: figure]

Figura 6

En la casilla “Gestor de URL adicionales de tarjetas”, copie y pegue la siguiente dirección URL.

https://dl.espressif.com/dl/package_esp32_index.json

Si usted ya tenía una instalación previa para el NodeMCU ESP8266, puede agregar al ESP32, separando con coma los 2 links (Figura 7):

https://dl.espressif.com/dl/package_esp32_index.json,http://arduino.esp8266.com/stable/package_esp8266com_index.json

10

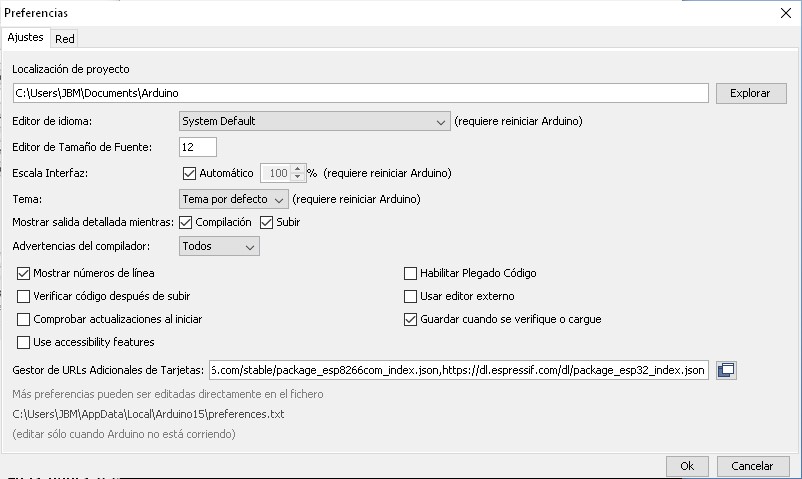
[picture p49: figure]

Figura 7

Elija ahora la opción “Herramientas”, ”Placa” (figura 8) y aparecerá una ventana de opciones. Hasta arriba en la lista, elija “Gestor de Tarjetas” y aparecerá otra lista con nuevas placas.

Escriba la ventana de localización “esp32” para que le muestre el paquete ESP32 de Espressif Systems en forma inmediata, como se muestra en la figura 9.

Dé click en “Instalar”. Una vez que el paquete está instalado verifique que se muestre el mensaje “INSTALLED” (figura 10).

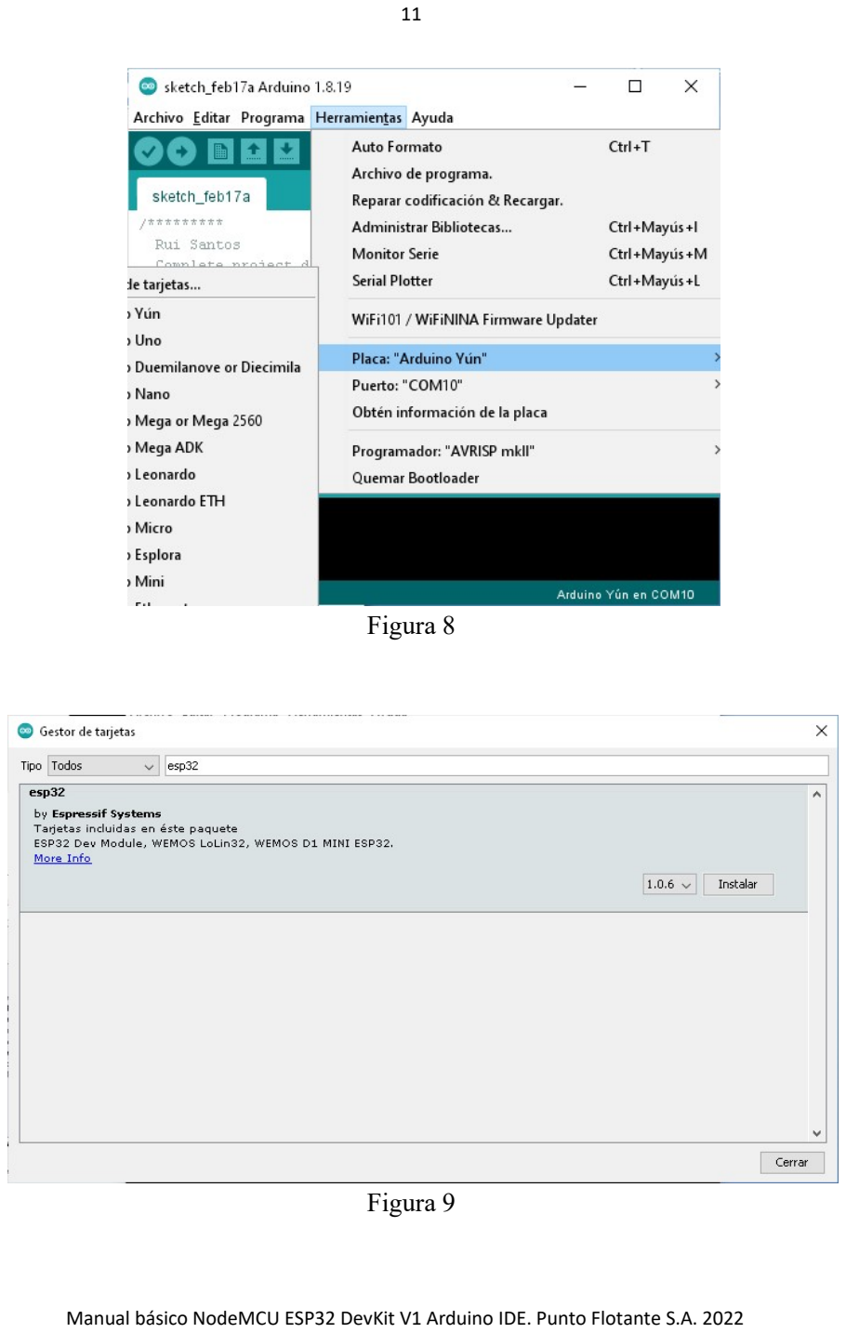
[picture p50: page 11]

11

Figura 8

Figura 9

12

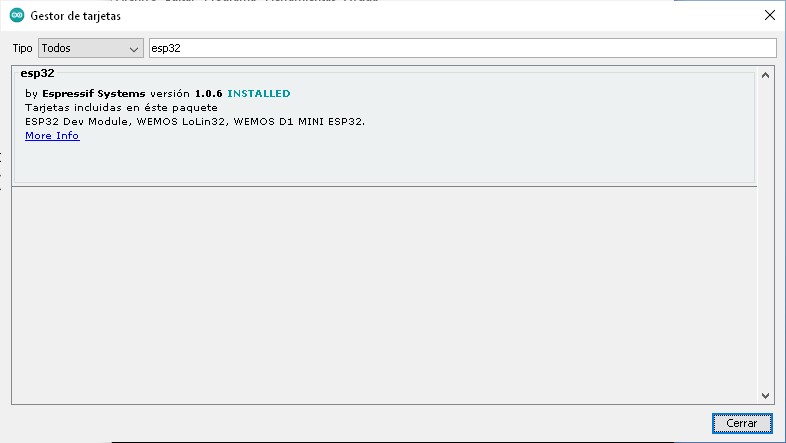
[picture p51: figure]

Figura 10

Una vez que el paquete ESP32 de Espressif Systems ha sido agregado al IDE, es necesario elegir el modelo del módulo. El procedimiento se muestra en la figura 11. Se elige “Herramientas”, “Placa”, “ESP32 Arduino” y finalmente, en nuestro caso se elige el módulo:
DOIT ESP32 DEVKIT V1

13

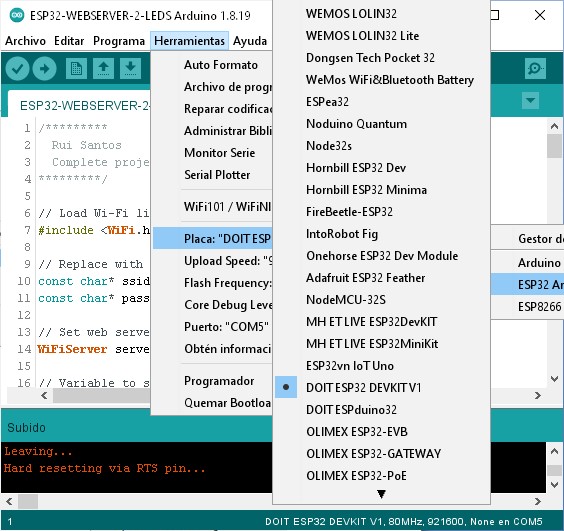
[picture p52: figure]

Figura 11

Hasta aquí termina la instalación del módulo en el IDE. Pase al siguiente capítulo para instalar el driver del circuito USB-Serial.

5. Dar de alta el driver USB-Serial CP2102.

Inserte el cable Micro USB a su computadora (en cualquier puerto USB) y al conector del módulo ESP32 (figura 3)

14

El módulo tiene integrado un circuito convertidor de USB a Serial CP2102. Es necesario cargar el driver en la computadora PC de tal manera que dicho circuito sea reconocido como un puerto serial COM por el administrador de dispositivos. Baje el driver aquí:

https://puntoflotante.net/CP210x_VCP_Windows.zip

Extraiga los archivos del formato .zip y abra la carpeta del driver. En computadora Windows 10, ejecute el archivo “CP210xVCPInstaller_x64.exe” para instalar el driver.

Una vez instalado, conecte el cable Micro USB del módulo ESP32 al puerto de su computadora. Ahora abra el administrador de dispositivos y deberá mostrar la ventana con el puerto serial COM asignado. En este ejemplo se trata del COM5. En su computadora podría asignarse otro número del puerto (figura 12).

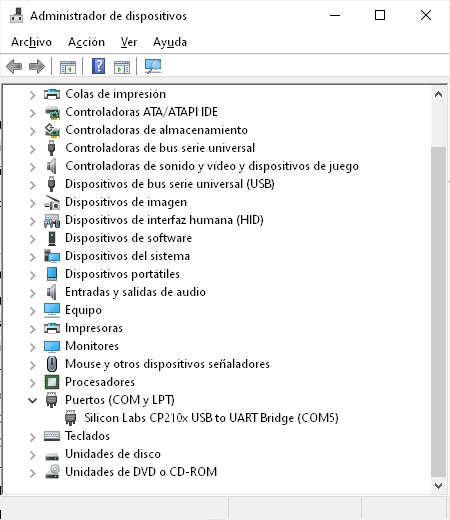
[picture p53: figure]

Figura 12

15

6. Programa de prueba Blink Led.

Finalmente, como prueba final de la instalación, realizaremos la carga de un sencillo programa, utilizando el led azul integrado al módulo (conectado a la salida GPIO2).

El led está onboard de tal manera que no es necesario realizar ningún alambrado adicional, como se muestra en la foto de la figura 3.

Baje el programa de prueba de este link y guarde el contenido extraído en una carpeta, como se muestra en la figura 13:

https://puntoflotante.net/BLINK-LED.zip

Abra el archivo BLINK-LED.ino

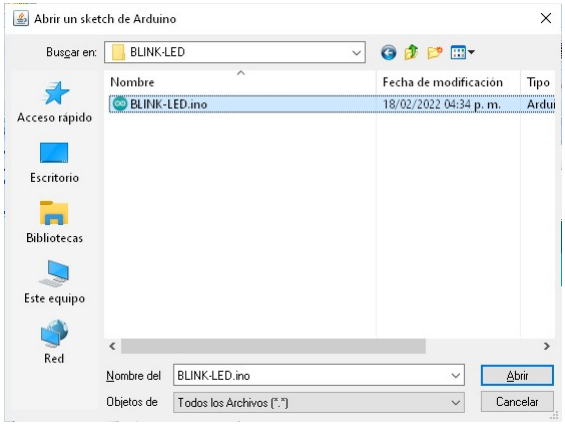
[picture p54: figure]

Figura 13

16

Se abrirá otra ventana en el IDE, como la mostrada en la figura 14, en donde puede observarse el archivo fuente.

Para cargar el programa ejecutable en el módulo ESP32, dé click en “Programa” y “Subir”. El IDE compila primeramente el archivo fuente y posteriormente envía el ejecutable al módulo, en donde corre automáticamente. Al final del proceso, usted observará el led azul parpadeando cada 500 ms.

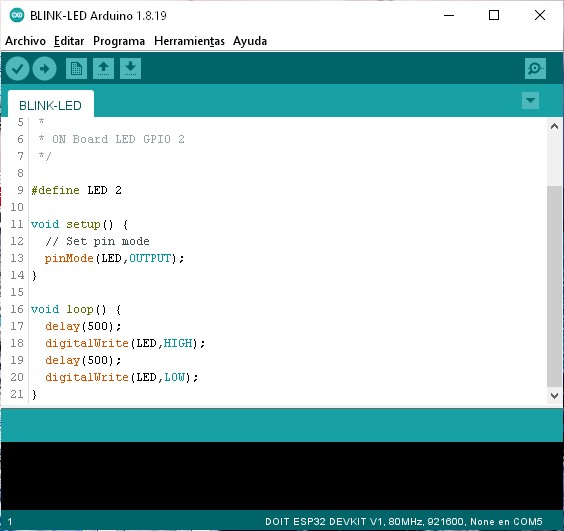
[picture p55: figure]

Figura 14

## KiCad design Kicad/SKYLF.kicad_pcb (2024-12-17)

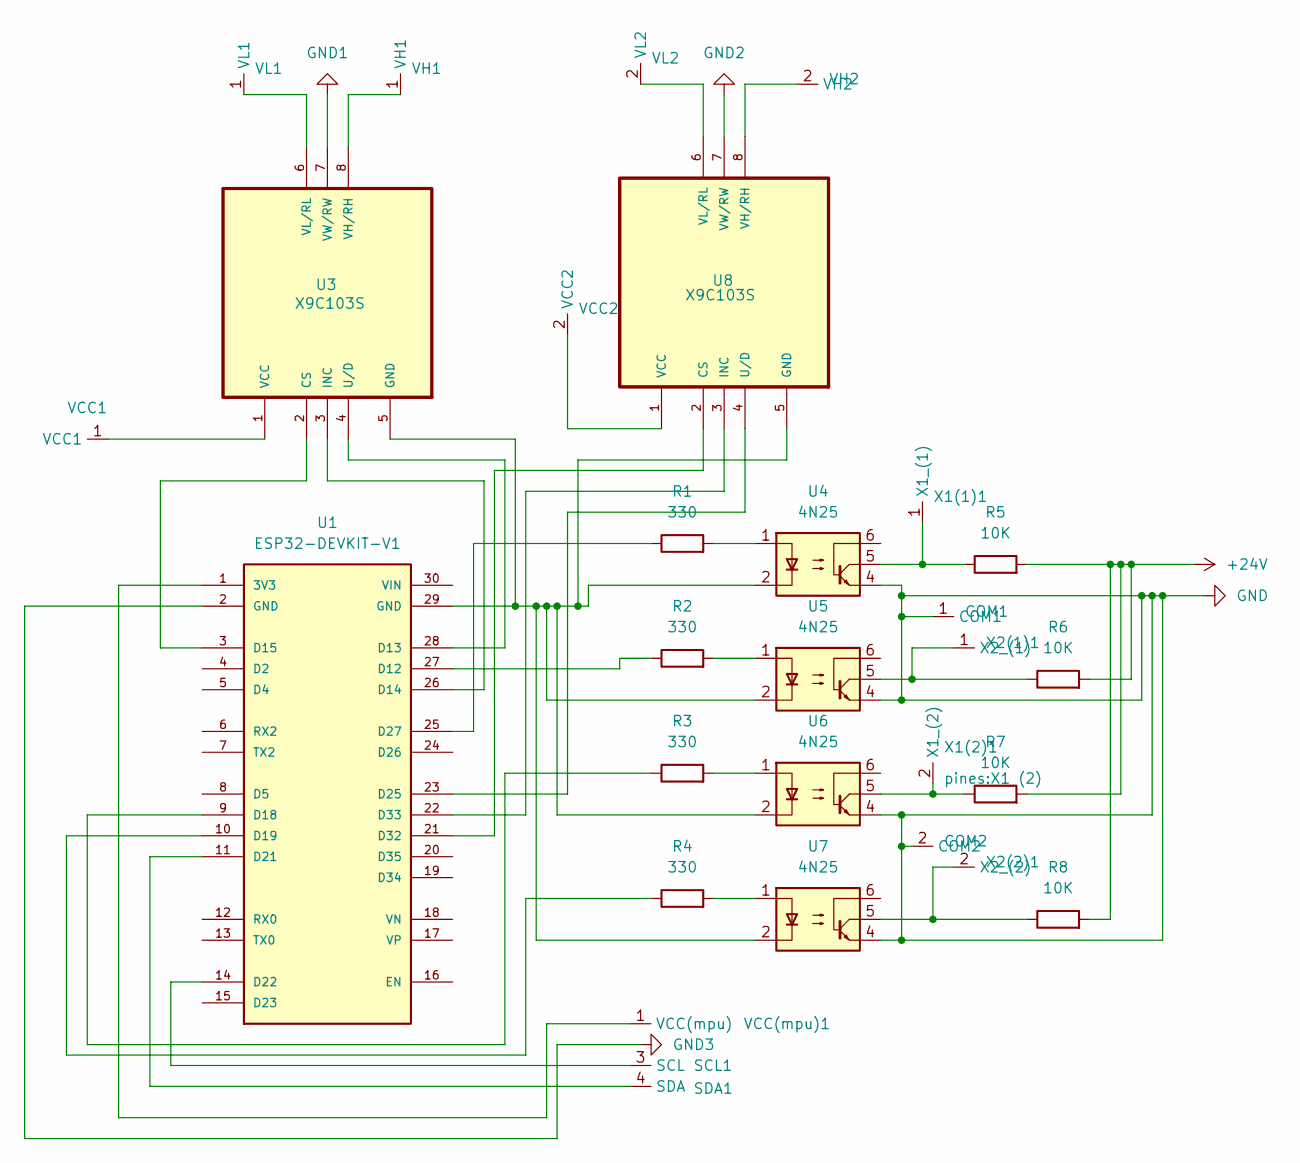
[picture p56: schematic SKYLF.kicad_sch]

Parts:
COM1: COM1
COM2: COM2
R1, R2, R3, R4: 330; R_Axial_DIN0309_L9.0mm_D3.2mm_P12.70mm_Horizontal
R5, R6, R7, R8: 10K; R_Axial_DIN0309_L9.0mm_D3.2mm_P12.70mm_Horizontal
SCL1: SCL
SDA1: SDA
U1: ESP32-DEVKIT-V1; MODULE_ESP32_DEVKIT_V1; PARTREV N/A
U3, U8: X9C103S; Potenciometro X9C103S; MPN X9C103S
U4, U5, U6, U7: 4N25; DIP-6_W7.62mm
VCC1: VCC1
VCC2: VCC2
VCC(mpu)1: VCC (mpu)
VH1: VH1
VH2: VH2
VL1: VL1
VL2: VL2
X1(1)1: X1 (1)
X1(2)1: X1 (2)
X2(1)1: X2 (1)
X2(2)1: X2 (2)

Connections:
+24V: R5.2, R6.2, R7.2, R8.2
GND: COM1.1 (COM1), COM2.2 (COM2), U4.4, U5.4, U6.4, U7.4
GND1: U3.7 (VW/RW)
GND2: U8.7 (VW/RW)
GND3: U1.2 (GND)
unnamed: R1.2, U4.1
unnamed: R2.2, U5.1
unnamed: R3.2, U6.1
unnamed: R4.2, U7.1
unnamed: SCL1.3 (SCL), U1.14 (D22)
unnamed: SDA1.4 (SDA), U1.11 (D21)
unnamed: U1.1 (3V3), VCC(mpu)1.1 (VCC(mpu))
unnamed: R2.1, U1.27 (D12)
unnamed: U1.28 (D13), U3.4 (U/D)
unnamed: U1.26 (D14), U3.3 (INC)
unnamed: U1.3 (D15), U3.2 (CS)
unnamed: R3.1, U1.9 (D18)
unnamed: R4.1, U1.10 (D19)
unnamed: U1.23 (D25), U8.4 (U/D)
unnamed: R1.1, U1.25 (D27)
unnamed: U1.21 (D32), U8.2 (CS)
unnamed: U1.22 (D33), U8.3 (INC)
unnamed: U1.29 (GND), U3.5 (GND), U4.2, U5.2, U6.2, U7.2, U8.5 (GND)
unnamed: U3.1 (VCC), VCC1.1 (VCC1)
unnamed: U3.8 (VH/RH), VH1.1 (VH1)
unnamed: U3.6 (VL/RL), VL1.1 (VL1)
unnamed: U8.1 (VCC), VCC2.2 (VCC2)
unnamed: U8.8 (VH/RH), VH2.2 (VH2)
unnamed: U8.6 (VL/RL), VL2.2 (VL2)
unnamed: R5.1, U4.5, X1(1)1.1 (X1_(1))
unnamed: R7.1, U6.5, X1(2)1.2 (X1_(2))
unnamed: R6.1, U5.5, X2(1)1.1 (X2_(1))
unnamed: R8.1, U7.5, X2(2)1.2 (X2_(2))

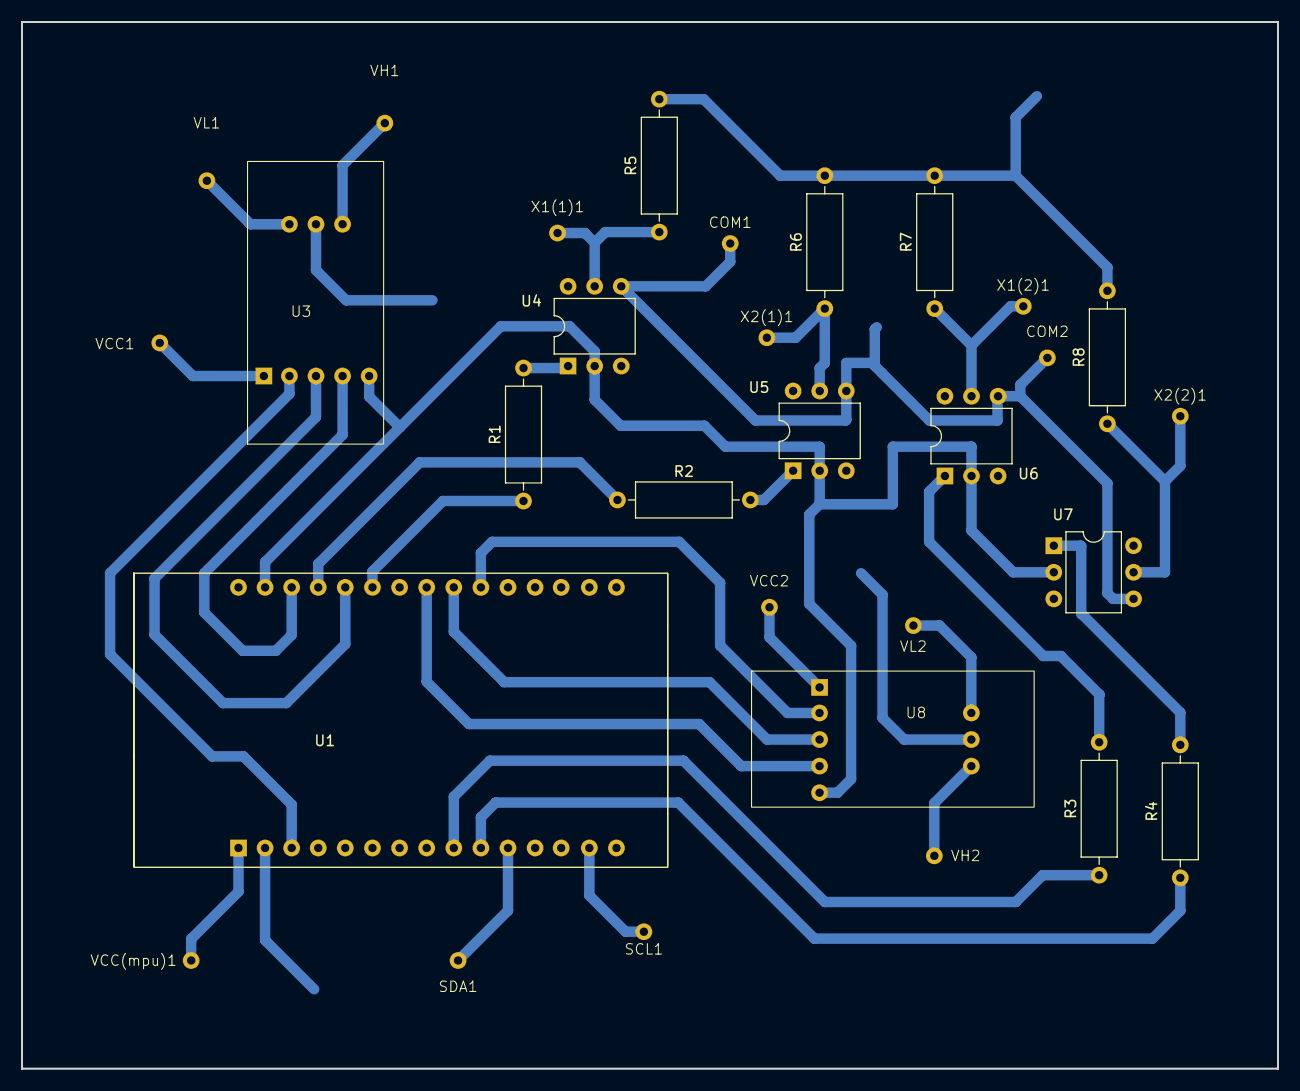
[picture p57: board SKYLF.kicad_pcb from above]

Board: 2 copper layers, 120.0 x 100.0 mm, 30 parts (0 on the bottom side), 30 nets.

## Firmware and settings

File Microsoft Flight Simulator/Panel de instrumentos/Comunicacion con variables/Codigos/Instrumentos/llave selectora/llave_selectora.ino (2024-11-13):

#include <Arduino.h>

int pin13 = 13;
int pin10 = 10;
int pin7 = 7;
int pin4 = 4;
int pin2 = 2;  // Botón conectado al pin 2

void setup() {
  Serial.begin(115200);
  pinMode(pin13, INPUT_PULLUP);
  pinMode(pin10, INPUT_PULLUP);
  pinMode(pin7, INPUT_PULLUP);
  pinMode(pin4, INPUT_PULLUP);
  pinMode(pin2, INPUT_PULLUP);  // Configurar pin 2 como entrada con pull-up interno
}

void loop() {
  int currentState = readSwitchState();

  // Comprobar si el botón conectado al pin 2 está presionado
  if (digitalRead(pin2) == LOW) {
    Serial.println(5);  // Estado START del magneto
    delay(1000); // Esperar 1 segundo
    currentState = readSwitchState();  // Leer nuevamente la posición de la llave selectora
    Serial.println(currentState);  // Enviar la posición actual de la llave selectora
  } else {
    Serial.println(currentState);
  }

  delay(250); // Esperar 250 ms para evitar demasiadas lecturas rápidas
}

// Función para leer el estado de la llave selectora
int readSwitchState() {
  if (digitalRead(pin13) == LOW) return 1;  // Low because of pull-up
  if (digitalRead(pin10) == LOW) return 2;
  if (digitalRead(pin7) == LOW) return 3;
  if (digitalRead(pin4) == LOW) return 4;
  return 0;  // Estado desconocido
}

void serialEvent() {
  while (Serial.available()) {
    String command = Serial.readStringUntil('\n');
    if (command == "READ_STATE") {
      Serial.println(readSwitchState());  // Enviar el estado actual de la llave selectora
    }
  }
}

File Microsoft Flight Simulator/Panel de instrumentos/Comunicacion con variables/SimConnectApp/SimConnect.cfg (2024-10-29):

; Example SimConnect client configurations

; new FS pipe
[SimConnect]
Protocol=Pipe
Port=Custom/SimConnect
Address=127.0.0.1

; Automatic detection, backward compatible with FSX
[SimConnect.1]
Protocol=Auto
Address=
Port=
MaxReceiveSize=
DisableNagle=

[SimConnect.2]
Protocol=Ipv6
Port=501
Address=127.0.0.1

[SimConnect.3]
Protocol=Ipv4
Address=127.0.0.1
Port=500

; default FSX pipe
[SimConnect.4]
Protocol=Pipe
Address=.

; global pipe, use the configuration of the remote server
[SimConnect.4]
Protocol=Pipe
Address=<remote computer address or name here>
Port=<remote computer pipe name (matches Port name given in SimConnect.xml)>

; global IPv6, use the configuration of the remote server
[SimConnect.5]
Protocol=IPv6
Address=<remote computer address or name here>
Port=<remote computer port number here>

; global IPv4, use the configuration of the remote server
[SimConnect.6]
Protocol=IPv4
Address=<remote computer address or name here>
Port=<remote computer port number here>

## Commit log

2024-11-06 Create Comprobante de compra.pdf
2024-11-06 Create Partes del pimer panel de control (Cessna 152).docx
2024-11-11 Factura de compra cables macho-macho
2024-11-11 Factura de compra 10 tornillos y arandelas
2024-11-15 cambio de nombre
2024-11-15 Create Nuevo Documento de texto.txt
2024-11-15 Codigo de pueba N° entre el ESP32 y el Pote digital
2024-11-15 Codigo de pueba N°1 entre el ESP32 y el Pote digital
2024-11-15 Create Codigo de pueba N°2 entre el ESP32 y el Pote digital
2024-11-15 Create Codigo de pueba N°1 entre el ESP32 y el Pote digital con el MPU6050
2024-11-15 Create Codigo de pueba N°2 entre el ESP32 y el Pote digital con el MPU6050
2024-11-15 Create Codigo de pueba N°3 entre el ESP32 y el Pote digital con el MPU6050
2024-11-15 Create Codigo de pueba N°4 entre el ESP32 y el Pote digital con el MPU6050
2024-11-15 Create Codigo de pueba N°5 entre el ESP32 y el Pote digital con el MPU6050 (con un filtro)
2024-11-21 imagenes de la pagina web
2024-11-26 Create Factura de compra disco de corte para amoladora.pdf
2024-11-27 Create factura placa de cobre.pdf
2024-11-27 Github de todos los integrantes
2024-11-27 gmail de contacto de cada integrante en la caratula del github
2024-11-27 Contactos de cada integrante en la caratula del Github
2024-11-27 Organización de la distribución de la caratula del GitHub
2024-11-27 Foto grupal de SKYLF
2024-11-27 Video de Presentación SKYLF
2024-11-27 Create Perilla 3D para Magneto.stl
    [Perilla 3D para Magneto.stl]
2024-11-27 Organizar laa carpetas de panel de control en el github
2024-11-27 Create Panel Cessna152 sin logo.stl
    [Panel Cessna152 sin logo.stl]
2024-11-27 Create PanelDeControlCessna152 SkylF con logo.stl
    [PanelDeControlCessna152 SkylF con logo.stl]
2024-11-28 Factura de compra scaneada de MPU6050 del 14-10
2024-11-28 Create FdC CableHDMI_DisplayPortAHdmi.pdf
2024-11-28 Create Esquemático de Conexiones y Fuente de Alimentación .png
2024-11-28 Create Placa PCB con sus huellas correspondientes de cada componente.png
2024-11-28 Create Arduino Brizu.mfmc
2024-11-28 Create Panel de Control.mfmc
2024-11-28 Create intento de conexion.mcc
2024-11-28 Create Gasto Total de SKYLF.pdf
2024-11-28 Update Gasto Total de SKYLF.pdf
2024-11-29 Create Elementos de alcance inconclusos SkylF.docx
2024-12-11 Create DIAGRAMA ARDUINO.png
2024-12-11 Plantilla de gastos del proyecto
2024-12-17 Create Contenido para Story del Panel de Control.mp4
2024-12-17 feat: agregar carpeta de campo
2024-12-19 Gasto total de SKYLF
